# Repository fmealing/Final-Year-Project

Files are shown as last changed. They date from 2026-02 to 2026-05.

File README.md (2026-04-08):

# Ghost Glove

**Progress you can see.**

A smart gym glove that automatically tracks strength training sessions in real time, built as a Final Year Project for MEng Mechatronic and Robotic Engineering at the University of Birmingham.

> By Mealing Labs

---

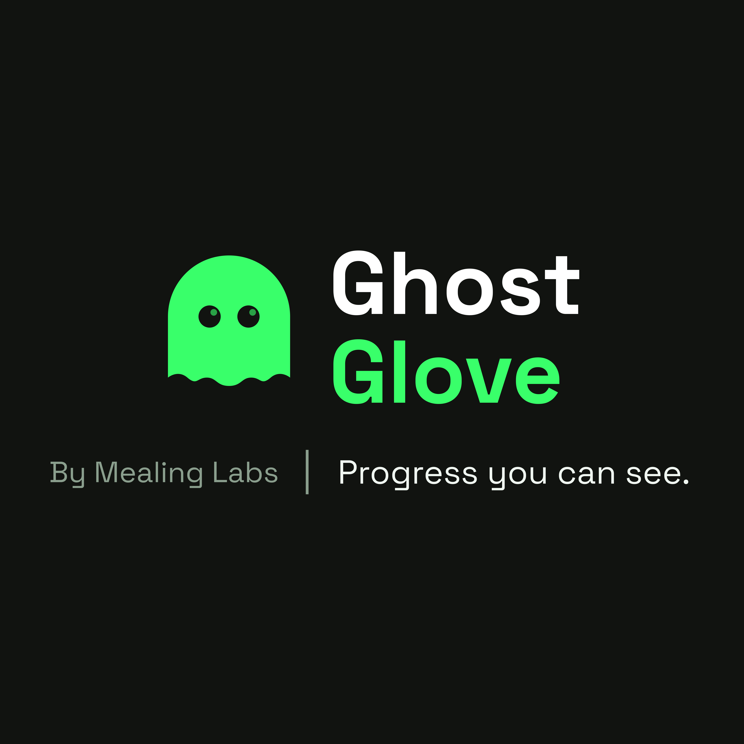
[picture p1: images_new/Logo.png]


---

## The Idea

Most people who join the gym quit. Not because they lack motivation, but because they cannot see the progress. Numbers in a notebook feel abstract. Comparing yourself to others feels worse.

Ghost Glove solves this by changing the question: **what if your only opponent was your past self?**

Every session the glove records your performance and builds a ghost, a data-driven avatar of who you were. Over time, you race against previous versions of yourself. The gap is small at first. But it is real, and you cannot argue with it.

---

## User Story

> Jamie joined the gym in January. Not for the first time. Third time, actually.

Jamie is 24. The first two times he went hard for about three weeks, got bored, stopped seeing the point, and quietly let the membership lapse. This time he bought the glove because his flatmate would not stop talking about it.

**Day 1**<br>
He opens the app, pairs the glove, and gets told something he does not expect. "Your first session builds your opponent." There is no pressure, no benchmark to hit. He just trains, and the app watches. At the end he sees his avatar for the first time: weak, minimal gear, barely any aura. The app tells him: "This is January Jamie. You are going to make him irrelevant." He thinks it is a bit corny. He also screenshots it.

**Week 1**<br>
He trains twice. Nothing dramatic. The audio cues during sets are strange at first. But on his third session it tells him "you slowed down here last time" at rep six of a dumbbell row, and he pushes to rep eight out of pure stubbornness. He does not think much of it in the moment. But he remembers it on the walk home.

**Week 2**<br>
His consistency gear updates. Small change to the avatar, slightly better armour. He notices. He has not missed a session yet and the app reflects that without making a big deal of it. He shows his flatmate. His flatmate points out his ghost still looks terrible. Jamie goes to the gym the next morning.

**Week 3**<br>
First real ghost comparison drops. Current Jamie vs Week 1 Jamie on the same exercise. The gap is small but real: three more quality reps at the same weight. At the end of the set the app says: "you beat him." No fanfare. Just that. He stares at his phone for a second. This is the moment, not because the progress is huge, but because for the first time the progress is his, measured against himself.

**Week 6**<br>
Jamie is training three times a week now. He did not decide to; it just happened. Some sessions he loses, and the app does not punish him for it. It just updates the data. He has stopped thinking about what other people in the gym can lift. He has got his own thing to beat.

**Six months in**<br>
The six-month ghost appears for the first time. January Jamie, full avatar, standing next to current Jamie. The difference is visible across all three axes: bigger build, full gear set, bright aura. Jamie sends it to his flatmate without saying anything. His flatmate buys a glove the next day.

---

## User Journey

The journey was designed before a single line of code was written. Three core phases:

| Phase | What Happens |
| --- | --- |
| **Select & Connect** | Choose your workout. App loads your targets. Put on the glove and everything connects automatically. |
| **Track & Respond**  | Reps counted automatically. App tracks proximity to failure in real time. |
| **Review & Evolve**  | Set complete. App adjusts the next target automatically and shows what you achieved. |

User Journey 1
User Journey 2
User Journey 3

_Initial concept sketches, 16/03/26_

---

## Gamification

The core mechanic: **you compete only against past versions of yourself.** Wins are genuine progress, not arbitrary points.

Your avatar evolves across three axes, each mapped to a real training metric:

| Axis | What It Measures | Visual Representation |
| --- | --- | --- |
| **Stronger** | Progressive weight increase | Physical build / muscle mass |
| **Consistent** | Session attendance and streak | Armour quality |
| **Intense** | Effort per session (velocity, proximity to failure) | Aura / energy |

The ghost system operates across two timescales: a **4-week ghost** (your recent self) and a **6-month ghost** (who you were at the start). Beating one feels like momentum. Beating the other feels like transformation.

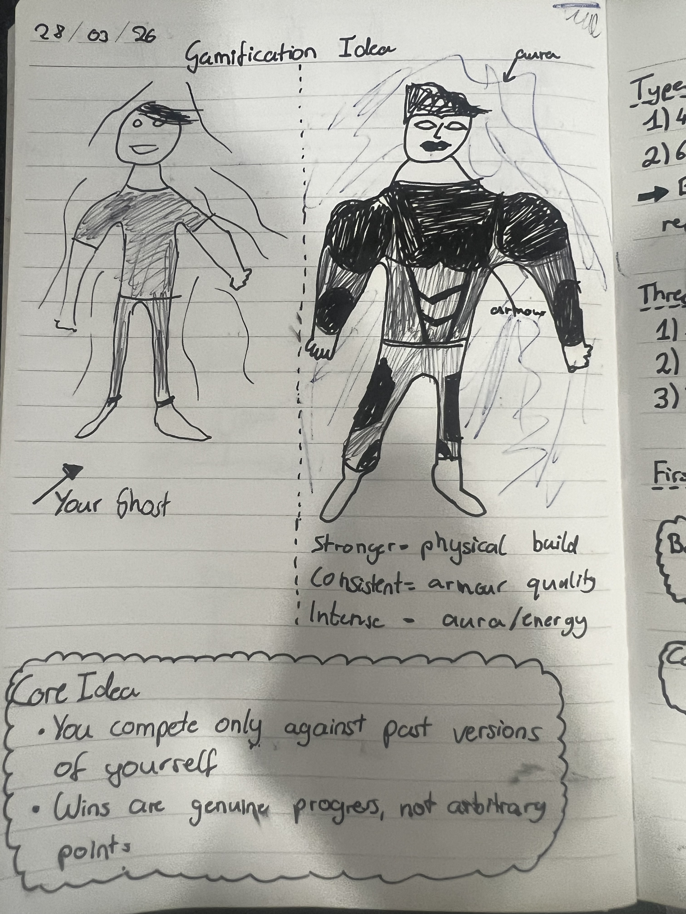
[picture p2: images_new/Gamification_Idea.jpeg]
Gamification Idea Sketch

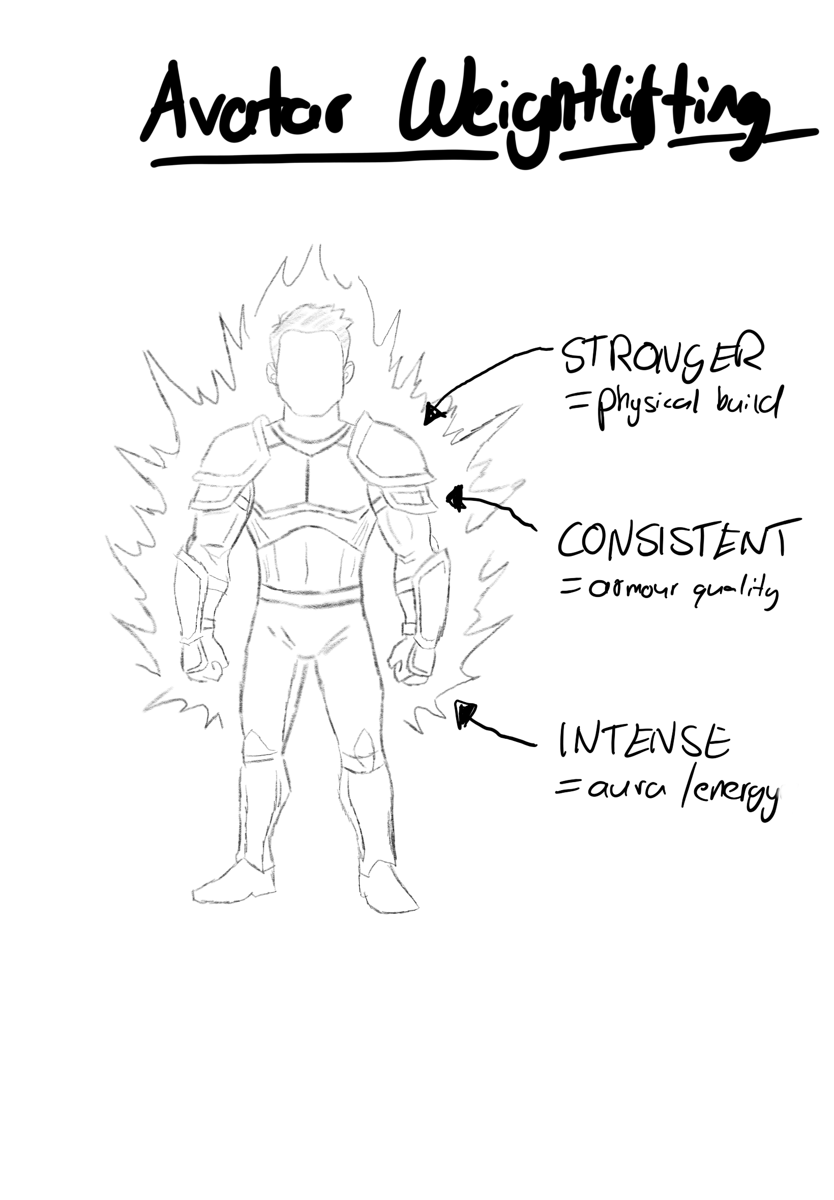
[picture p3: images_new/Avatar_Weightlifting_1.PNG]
Avatar Weightlifting Sketch

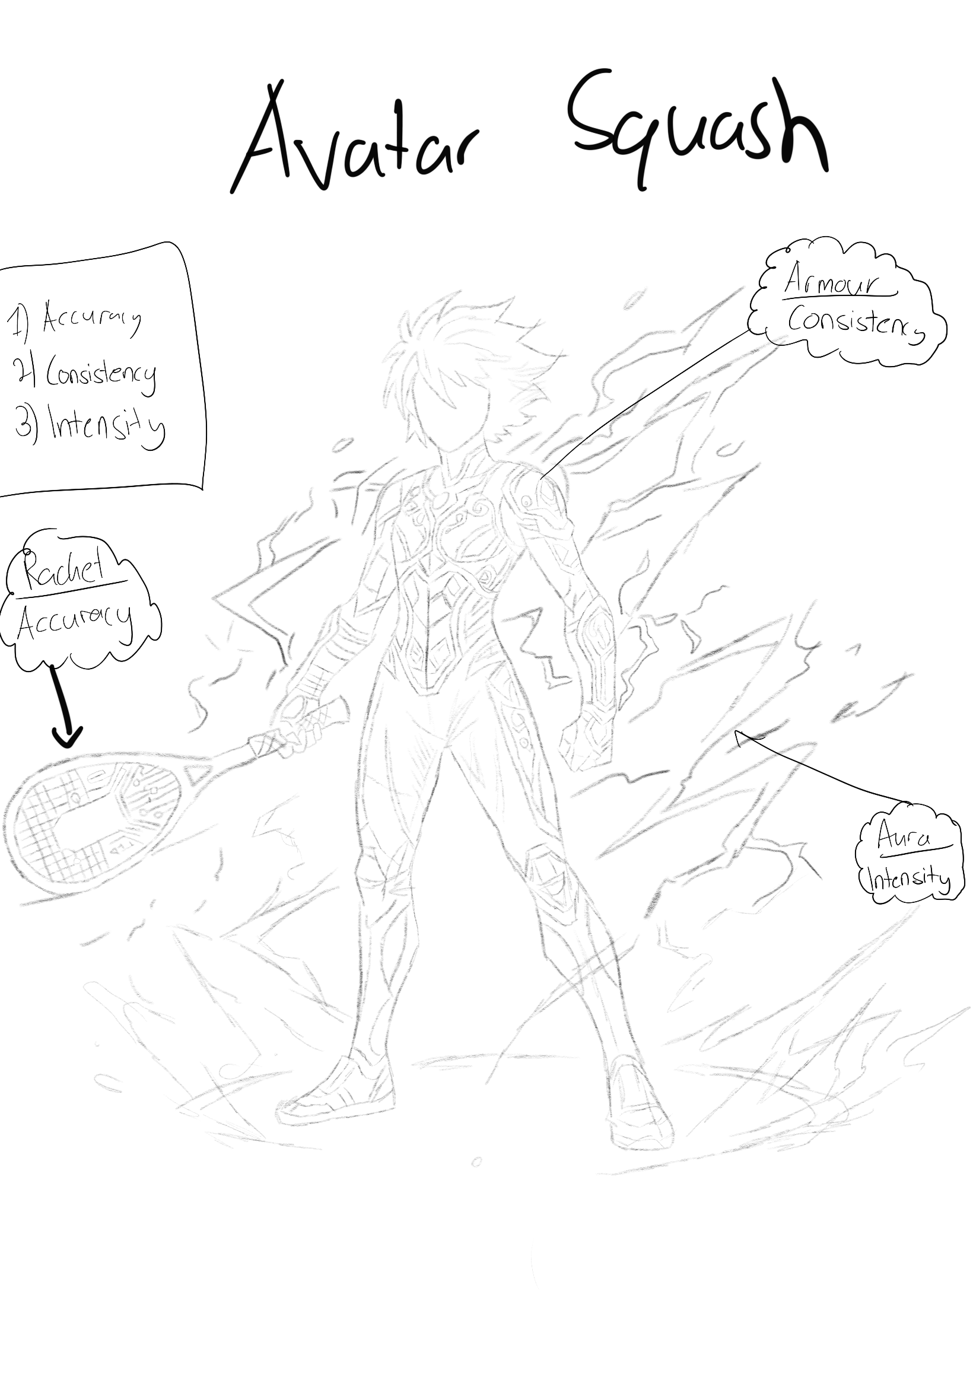
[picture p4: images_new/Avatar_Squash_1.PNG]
Avatar Squash Sketch


_Left: Original gamification concept (28/03/26). Right: Sport-specific avatar sketches. The system is designed to extend beyond weightlifting._

---

## Hardware

Ghost Glove is a fully manufactured smart glove with permanently soldered electronics. The sensor stack:

- **Flex Sensors (x4)**: measure finger bend angle via resistive voltage dividers. Resistor value: 47 kOhm, derived from a geometric mean of approximately 43.3 kOhm, near-optimal for mid-flex sensitivity.
- **MPU-6050 IMU**: 6-DOF accelerometer and gyroscope for wrist orientation and motion. Used for rep counting via a Madgwick filter.
- **ADS1115 ADC**: 16-bit external ADC. Resolves the ADC2/WiFi conflict inherent to the ESP32 by handling all analog reads independently.
- **ESP32-C3 Zero**: the microcontroller. Compact, BLE-capable, runs FreeRTOS with separate sensor tasks.

All components are mounted on a **5 cm x 7 cm veroboard**, permanently soldered and integrated into the glove.

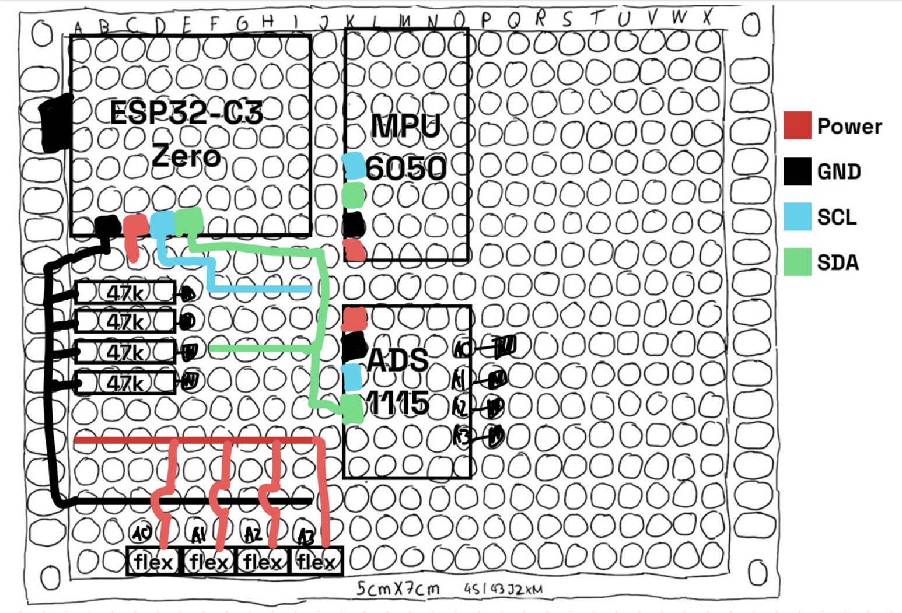
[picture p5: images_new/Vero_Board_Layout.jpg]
Veroboard Layout

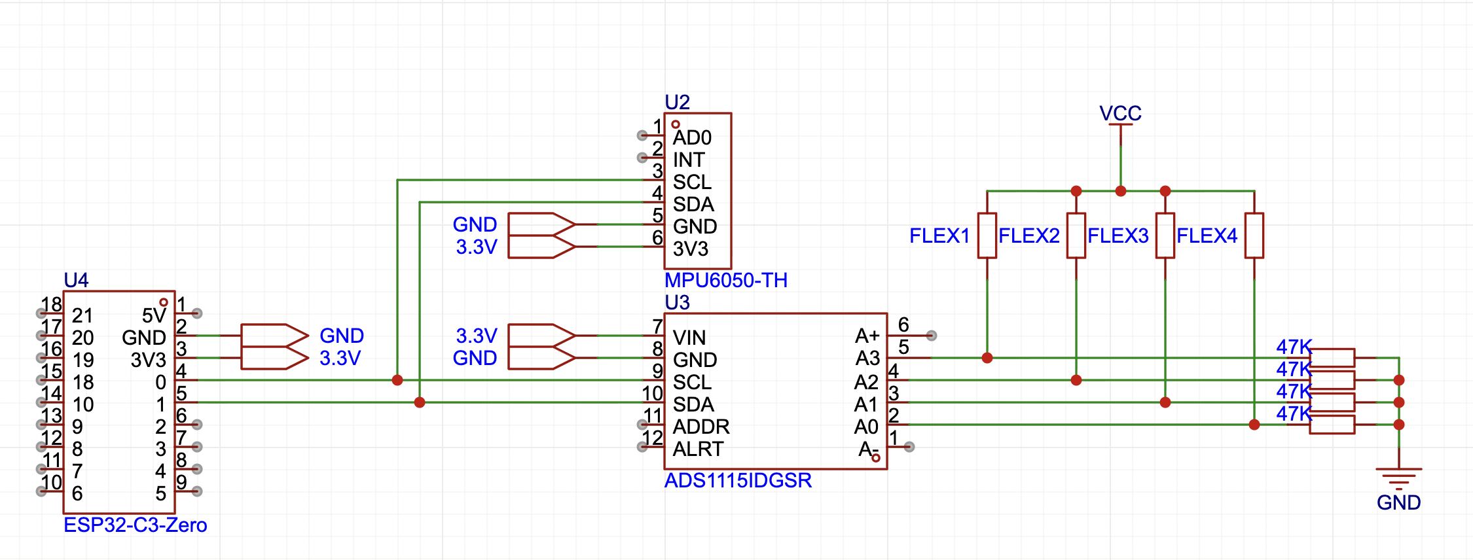
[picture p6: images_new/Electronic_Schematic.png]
Electronic Schematic


_Left: Hand-drawn veroboard layout. Right: EasyEDA schematic showing ESP32-C3 Zero, MPU-6050, ADS1115, and flex sensor voltage dividers._

---

## System Architecture

```
[Flex Sensors] --+
                 +---> [ADS1115 ADC] --+
[MPU-6050 IMU] --+                    |
                                      v
                              [ESP32-C3 Zero]
                              FreeRTOS Tasks:
                              - Sensor read task
                              - IMU read task
                              - MQTT publish task
                                      |
                                      v  MQTT over WiFi
                               [HiveMQ Broker]
                                      |
                                      v
                              [NeonSQL Database]
                                      |
                                      v
                          [Flask API (AWS)] --> [Web Dashboard]
```

Data flow has been validated end-to-end. Upload frequency is approximately 0.31 Hz, with inter-sample jitter of around 237 ms from WiFi scheduling. The live web dashboard displays real-time rep counts and sensor readings.

---

## Software

### Firmware (ESP32-C3 / Arduino)

- **FreeRTOS** task architecture with separate threads for IMU read, ADC read, and MQTT publish
- **Madgwick filter** for orientation estimation from raw IMU data
- **I2C bus** shared between MPU-6050 and ADS1115
- **MQTT** publish to HiveMQ cloud broker

### Backend

- **HiveMQ**: Cloud MQTT broker
- **NeonSQL**: PostgreSQL-compatible serverless database
- **Flask API**: Hosted on AWS, bridges MQTT data to the web dashboard

### Dashboard

Live web interface showing rep counts and sensor readings in real time.

---

## Results

| Metric | Result |
| --- | --- |
| Rep counting accuracy | ~61% (averaged over 4 sets) |
| IMU pipeline | Fully validated; raw accelerometer and gyroscope data confirmed |
| Connectivity | ESP32 to HiveMQ to NeonSQL to Flask to Dashboard: working |
| Upload frequency | ~0.31 Hz |
| Glove manufacture | Veroboard permanently soldered and integrated |
| Flex sensors | Hardware fault under investigation; returning null values |

The system works reliably on slow, controlled reps. Fast or jerky movements cause false positives due to threshold sensitivity. Threshold tuning for dynamic rep detection is the primary in-progress item.

---

## Design System

The app has a defined visual language built to feel like a training tool, not a health tracker.

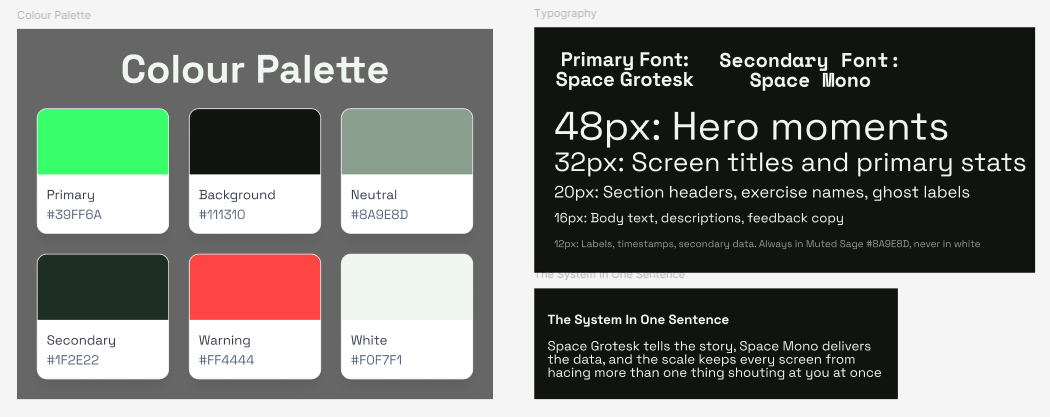
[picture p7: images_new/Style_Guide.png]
Style Guide


| Token | Value |
| --- | --- |
| Primary (Electric Green) | `#39FF6A` |
| Background | `#111310` |
| Secondary | `#1F2E22` |
| Neutral (Muted Sage) | `#8A9E8D` |
| Warning | `#FF4444` |
| Primary Font | Space Grotesk |
| Secondary Font | Space Mono |

Space Grotesk carries the narrative. Space Mono delivers the data. The type scale ensures no single screen has more than one element competing for attention.

---

## Future Work

### Hardware

- [x] Resolve flex sensor hardware fault and investigate null value root cause
- [ ] Custom PCB to replace veroboard and reduce enclosure size
- [ ] Piezoresistive TPU filament as an alternative flex sensing material
- [ ] Pressure Sensor Design 2: per-finger air bladder system with thin-profile construction

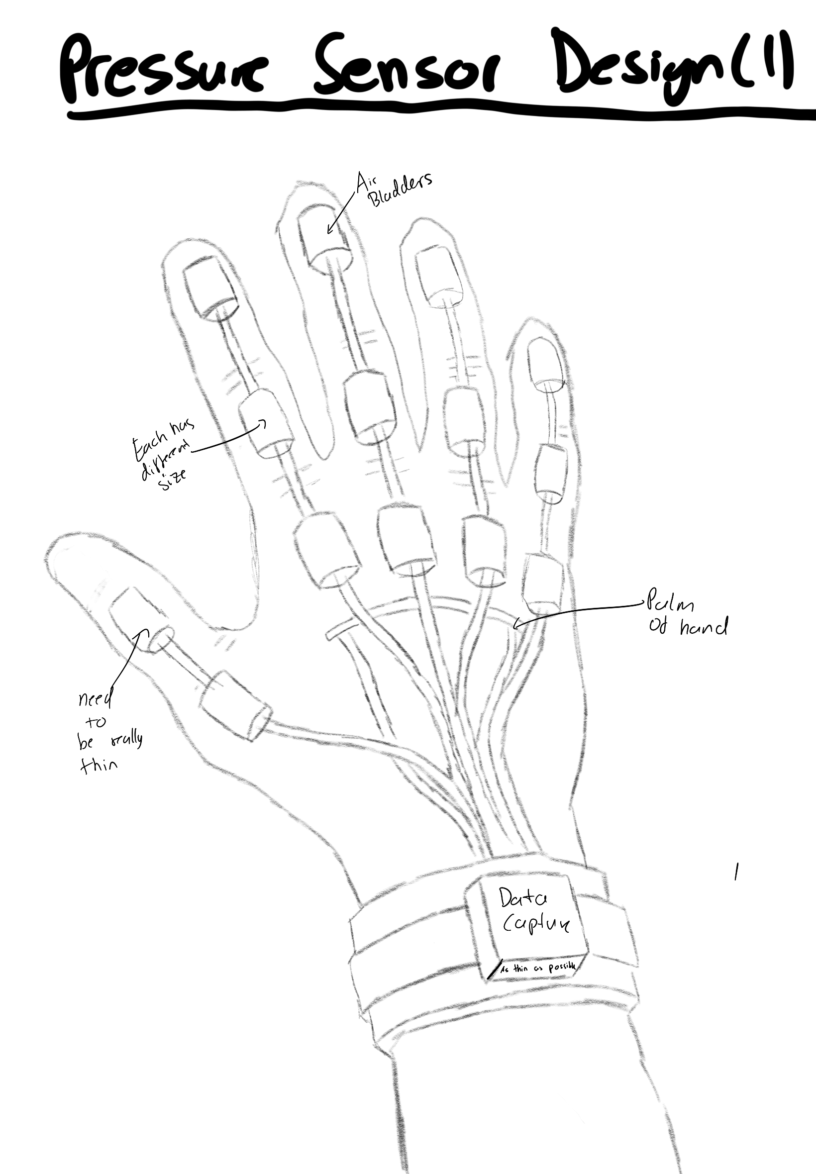
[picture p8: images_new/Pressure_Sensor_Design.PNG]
Pressure Sensor Design


_V3 concept: per-finger air bladders with joint-level pressure sensing. Each bladder is sized differently and routes to a wrist-mounted data capture unit._

### Software

- [ ] Threshold tuning for dynamic rep detection
- [ ] Matrix profiling for weight estimation from sensor data
- [ ] Ghost avatar system (4-week and 6-month comparisons)
- [ ] Mobile app (React Native) with Hale health score integration
- [ ] BLE transport to replace WiFi/MQTT for lower latency

---

## Academic Context

This project was submitted as a Final Year Project for the MEng Mechatronic and Robotic Engineering degree at the University of Birmingham, under the supervision of **Dr Mahvish Nazir**.

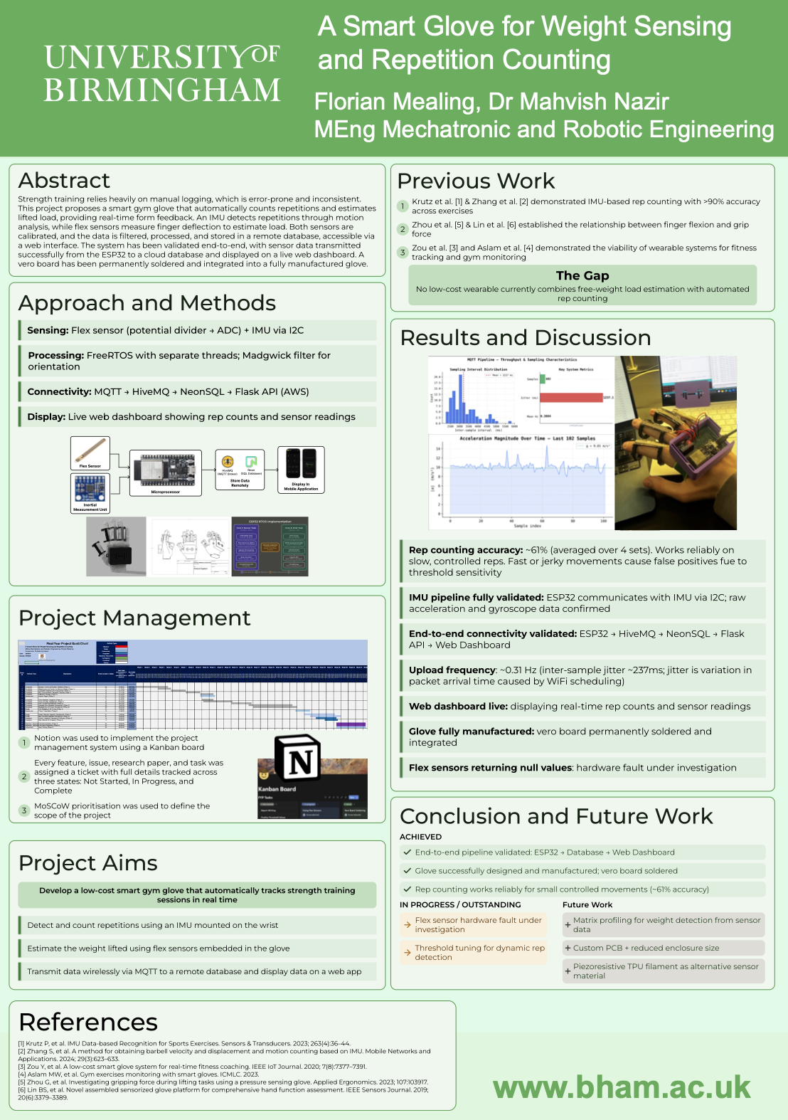
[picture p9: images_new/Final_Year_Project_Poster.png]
FYP Poster


**TRL Assessment: TRL 3**: subsystems validated independently. Simultaneous flex sensor and IMU transmission has been identified as the key hardware blocker preventing TRL 4.

**Project management:** Notion Kanban board with MoSCoW prioritisation. Every feature, issue, research paper, and task tracked across Not Started / In Progress / Complete.

---

## References

1. Krutz P, et al. _IMU Data-based Recognition for Sports Exercises._ Sensors & Transducers. 2023.
2. Zhang S, et al. _A method for obtaining barbell velocity and displacement and motion counting based on IMU._ Mobile Networks and Applications. 2024.
3. Zou Y, et al. _A low-cost smart glove system for real-time fitness coaching._ IEEE IoT Journal. 2020.
4. Aslam MW, et al. _Gym exercises monitoring with smart gloves._ ICMLC. 2023.
5. Zhou G, et al. _Investigating gripping force during lifting tasks using a pressure sensing glove._ Applied Ergonomics. 2023.
6. Lin BS, et al. _Novel assembled sensorized glove platform for comprehensive hand function assessment._ IEEE Sensors Journal. 2019.

---

## Author

**Florian Mealing** -- MEng Mechatronic and Robotic Engineering, University of Birmingham (2022--2026)

- [florianmealing.com](https://florianmealing.com)
- [LinkedIn](https://linkedin.com/in/florianmealing)
- [YouTube](https://www.youtube.com/@florianmealing)

---



_By Mealing Labs_

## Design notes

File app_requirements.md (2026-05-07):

# Ghost Glove — App & Backend Requirements

> For Claude Code. App-side only. ESP32 firmware is out of scope for this document.

---

## ⚠️ Architecture Change Notice

**The previous implementation had the ESP32 make direct API calls over WiFi. This is no longer the case.**

The data pipeline has fundamentally changed:

```
OLD: ESP32 → WiFi → API → NeonSQL
NEW: ESP32 → BLE → Mobile App → Backend API → NeonSQL
```

The **HiveMQ MQTT broker** and **NeonSQL database** are being retained, but the ESP32 no longer connects to them directly. The mobile app now owns the BLE connection and is responsible for forwarding data upstream.

Any existing code that assumed ESP32 → API direct calls should be treated as deprecated and replaced.

---

## BLE Data Packet

The ESP32 transmits a single structured packet per rep/interval over BLE. The app must parse this packet:

| Field | Type | Notes |
| --- | --- | --- |
| `accel_x` | float  | m/s² |
| `accel_y` | float  | m/s² |
| `accel_z` | float  | m/s² |
| `gyro_x` | float  | deg/s |
| `gyro_y` | float  | deg/s |
| `gyro_z` | float  | deg/s |
| `flex_1` | float  | Thumb (raw ADC or mapped voltage) |
| `flex_2` | float  | Index |
| `flex_3` | float  | Middle |
| `flex_4` | float  | Ring |
| `rep_count` | int | Cumulative rep count from ESP32 |
| `timestamp` | uint32 | Milliseconds since session start (used for speed/tempo analysis) |

---

## Tech Stack

- **Framework:** React Native (Expo) — consistent with existing Hale app work
- **BLE:** `react-native-ble-plx` or Expo's BLE module
- **Backend:** New lightweight backend, **hosted for free** (options: Railway free tier, Render free tier, or Supabase Edge Functions)
- **Database:** NeonSQL (existing, retain)
- **Broker:** HiveMQ (existing, retain) — app publishes to MQTT topics via backend or directly
- **Fonts:** Space Grotesk (primary), Space Mono (secondary) — load via `@expo-google-fonts`

---

## Design System

Match the Ghost Glove brand style guide exactly:

### Colours

```js
const colours = {
  primary: "#39FF6A", // Electric green — CTAs, active states, highlights
  background: "#111310", // Near-black — all screens
  secondary: "#1F2E22", // Dark green — cards, panels
  neutral: "#8A9E8D", // Muted sage — labels, timestamps, secondary data (NEVER white at 12px)
  warning: "#FF4444", // Red — errors, alerts
  white: "#F0F7F1", // Off-white — body text
};
```

### Typography

```js
// All sizes in px (React Native: use these as fontSize values)
const type = {
  hero: 48, // Space Grotesk Bold — hero moments only
  title: 32, // Space Grotesk — screen titles, primary stats
  sectionHeader: 20, // Space Grotesk — section headers, exercise names, ghost labels
  body: 16, // Space Grotesk — body text, descriptions, feedback copy
  label: 12, // Space Mono — labels, timestamps, secondary data
  // ⚠️ Always render 12px in neutral (#8A9E8D), never white
};
```

### Design Principles

- Dark background on all screens (`#111310`)
- Minimal, clean — no visual clutter
- Primary green used sparingly as accent only
- Space Mono for all data readouts (monospaced for alignment)
- Space Grotesk for all narrative/UI text

---

## App Architecture (Data Flow)

```
ESP32-C3 (BLE peripheral)
    │
    │  BLE characteristic notify
    ▼
Mobile App (BLE central)
    ├── Parse BLE packet
    ├── Run flex sensor position lookup (finger mapping)
    ├── Display live values (IMU + flex)
    ├── Display rep count
    ├── Maintain ring buffer (last N packets)
    └── On session end / buffer flush → HTTP POST to Backend
            │
            ▼
        Backend API (free-hosted)
            ├── Receive session data
            ├── POST to NeonSQL (session records, rep logs)
            ├── Publish summary to HiveMQ MQTT topic
            └── Future: intensity calculations, ghost comparison data
```

---

## Feature Requirements

### F1 — BLE Connection

- Scan for and connect to ESP32-C3 peripheral (device name: `GhostGlove` or configurable)
- Subscribe to BLE characteristic for data notifications
- Handle reconnection gracefully (auto-reconnect on drop)
- Show connection status indicator on all screens

### F2 — Flex Sensor Display & Finger Position Lookup

- Display raw flex sensor values for all 4 sensors (Thumb, Index, Middle, Ring)
- Apply lookup table to map ADC/voltage value → finger position label
  - Position states (to define with lookup thresholds): `EXTENDED`, `PARTIAL`, `BENT`, `CLOSED`
  - Thresholds TBD via calibration — implement as a configurable constant object
- Display both raw value and mapped position label in the UI
- Visual representation of hand/finger state (simple indicator, not necessarily a 3D model at this stage)

### F3 — IMU Display

- Live display of all 6 IMU values (accel XYZ, gyro XYZ)
- Use Space Mono font for numerical readouts
- Update in real-time as BLE packets arrive

### F4 — Rep Counter Display

- Display current rep count (sourced from ESP32 packet, not recounted in app)
- Large, prominent — 48px hero treatment
- Session total visible at all times during active session

### F5 — Session Ring Buffer

- Maintain a rolling ring buffer of the last N BLE packets (N = configurable, default 300)
- Buffer used to batch-upload to backend without overwhelming the API on every packet
- Flush buffer: on session end, or when buffer hits max capacity, or on manual trigger

### F6 — Data Export — IMU Graph

- Generate a time-series graph of IMU data from session buffer
- Axes: time (x), acceleration/gyro values (y)
- Export as image (PNG) or shareable format
- Library: `react-native-chart-kit` or `Victory Native`

### F7 — Data Export — Flex Sensor Graph

- Generate time-series graph of all 4 flex sensor channels
- Same export mechanism as F6

### F8 — Backend Integration

- New backend service, hosted for free (Railway / Render / Supabase Edge Functions — pick one)
- Endpoints required:
  - `POST /session` — upload a completed session (metadata + packet array)
  - `GET /sessions` — retrieve historical sessions for a user
  - `GET /session/:id` — retrieve a specific session with full packet data
- Backend writes to NeonSQL and publishes summary to HiveMQ
- App authenticates requests with a simple API key or JWT (TBD)

### F9 — Historical Data View

- View past sessions retrieved from backend
- Show: date, rep count, session duration
- Tap to expand: view IMU + flex graphs for that session

---

## Screen Map

```
App
├── Home / Dashboard
│   ├── Connect button (BLE status)
│   ├── Last session summary
│   └── Start Session CTA
│
├── Live Session Screen
│   ├── Rep Counter (hero, 48px)
│   ├── Flex Sensor Panel (4 sensors, value + position label)
│   ├── IMU Panel (6 values, live)
│   └── End Session button
│
├── Session Review Screen
│   ├── Rep total
│   ├── IMU graph (exportable)
│   ├── Flex sensor graph (exportable)
│   └── Upload to backend / Save locally
│
└── History Screen
    ├── Session list
    └── Session detail (graphs + stats)
```

---

## Out of Scope (This Document)

- ESP32 firmware (separate requirements doc)
- Ghost avatar / gamification layer (future milestone)
- User authentication / accounts (future milestone)
- Anything related to the old WiFi / direct API call architecture

---

## Notes for Implementation

- Prioritise getting BLE parsing and live display working first (F1–F4) before backend work
- The flex sensor lookup table thresholds will need calibration passes — build the system as configurable from day one, not hardcoded
- Keep backend minimal — it only needs to store and retrieve data at this stage; intensity calculations are a future concern
- Ring buffer implementation should be decoupled from the display layer so it can be flushed independently
- Use NativeWind for stling, not CSS

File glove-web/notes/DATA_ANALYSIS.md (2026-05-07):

# Ghost Glove — Data Analysis Guide

Two data-collection tools are built into the glove-web dashboard.
Access them via the **Calibration** and **Latency** tabs in the nav bar.

> **Requirements:** Chrome or Edge (Web Bluetooth). Glove firmware flashed and advertising as `GhostGlove`.

---

## Experiment 1 — Flex Sensor Characterisation (`/calibration`)

### Purpose

Determine the raw ADS1115 ADC count range for each finger across six known
hand positions. The resulting min/max values feed directly into
`lib/flexCalibration.ts` to calibrate the flex bars on the dashboard.

### Hand Positions

| Label | Description |
| --- | --- |
| Hand flat on table | Fingers fully extended, palm down |
| 50 mm tube | Hand curled around a 50 mm diameter cylinder |
| 40 mm tube | Hand curled around a 40 mm diameter cylinder |
| 30 mm tube | Hand curled around a 30 mm diameter cylinder |
| 20 mm tube | Hand curled around a 20 mm diameter cylinder |
| Fist | Hand fully closed |

### Procedure

1. Open the **Calibration** tab.
2. Click **Connect Glove** and select `GhostGlove` from the browser dialog.
3. Select a hand position using the position buttons.
4. Hold your hand in that position (keep it still).
5. Click **Start Capture** — a 3-second countdown plays, then 10 seconds of
   data are recorded automatically.
6. When the capture finishes, inspect the per-finger stats table (min, max,
   range, mean). The chart shows all four flex sensors over the capture window.
7. Click **Export CSV** to download the raw time-series for that position.
8. Repeat steps 3–7 for every position.
9. Once all positions are captured, click **Export All CSV** in the
   _All Captures — Summary_ table to download a single summary file.

### Repeatability Check

To test repeatability:

1. Remove the glove, put it back on, repeat the same position.
2. Compare the new capture's min/max against the first. A stable sensor will
   show <5% deviation in mean ADC value between wearings.

### CSV Format

**Per-position file** (`flex_<position>.csv`):

```
t_s,flex_ring,flex_middle,flex_index,flex_thumb
0.000,4102,7543,4012,6311
0.020,4098,7551,4008,6298
...
```

**Summary file** (`flex_calibration_summary.csv`):

```
position,ring_min,ring_max,ring_range,ring_mean,middle_min,...
Hand flat on table,3901,4203,302,4052.1,...
50 mm tube,...
```

### Updating Calibration

After completing all captures, open `lib/flexCalibration.ts` and update
`FLEX_RANGES` with the observed min (flattest position) and max (fist) per finger:

```ts
export const FLEX_RANGES = {
  ring:   { min: <flat_min>, max: <fist_max> },
  middle: { min: <flat_min>, max: <fist_max> },
  index:  { min: <flat_min>, max: <fist_max> },
  thumb:  { min: <flat_min>, max: <fist_max> },
} as const;
```

---

## Experiment 2 — BLE Latency Analysis (`/latency`)

### Purpose

Measure the end-to-end delay between the ESP32 transmitting a BLE NOTIFY
packet and the browser receiving it. Reports mean, min, max, and standard
deviation.

### Method

The ESP32 timestamps each packet as `millis() - sessionStart` (ms since BLE
connection). The browser records the GATT connection time (`connectedAt`).
For each arriving packet:

```
latency_ms = Date.now() - connectedAt - packet.timestamp
```

This isolates the BLE transmission + OS scheduling delay, independent of
wall-clock differences between the ESP32 and the host machine.

### Procedure

1. Open the **Latency** tab.
2. Click **Connect Glove**.
3. Click **Start Recording** — packets are captured continuously.
4. Move naturally for 30–60 seconds (or as long as required).
5. Click **Stop** — the chart and statistics table appear.
6. Click **Export CSV** to download the full latency log.

### Interpreting the Chart

- **Flat, low line** — consistent low latency. Expected: 10–50 ms range.
- **Occasional spikes** — BLE connection events or OS scheduling jitter.
- **Upward drift** — clock skew between ESP32 crystal and system clock
  accumulating over a long session. Acceptable for sessions under 5 minutes.

### CSV Format

`ble_latency.csv`:

```
seq,esp_timestamp_ms,latency_ms
0,20,18.00
1,40,17.50
2,60,19.20
...
```

| Column | Description |
| --- | --- |
| `seq` | Packet sequence number (0-indexed) |
| `esp_timestamp_ms` | `millis() - sessionStart` from firmware |
| `latency_ms` | Computed transmission delay |

### Notes

- Packets with `latency_ms < 0` or `> 2000` are automatically discarded
  (clock alignment artefacts at session start).
- Run the experiment with the glove in typical use conditions — laptop on desk,
  glove worn normally — to get representative figures.
- Repeat the experiment 3× and average the means for a more robust result.

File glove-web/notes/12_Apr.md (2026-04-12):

## Flex sensor ranges

### Thumb

- Max: 9100
- Min: 4500

### Index

- Max: 5300
- Min: 3000

### Middle

- Max: 10000
- Min: 6300

### Ring

- Max: 5200
- Min: 3900

really small ranges, need to tune resistors

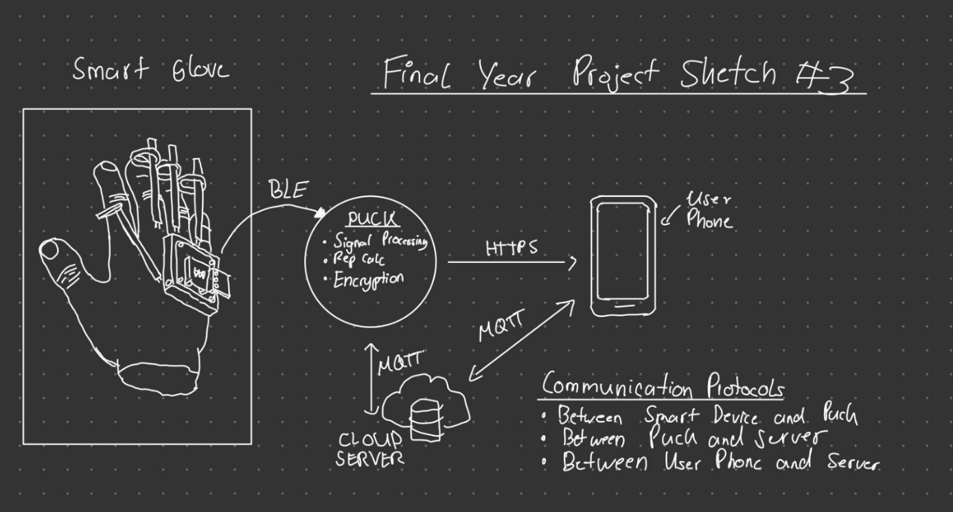
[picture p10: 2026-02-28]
images/architecture.png

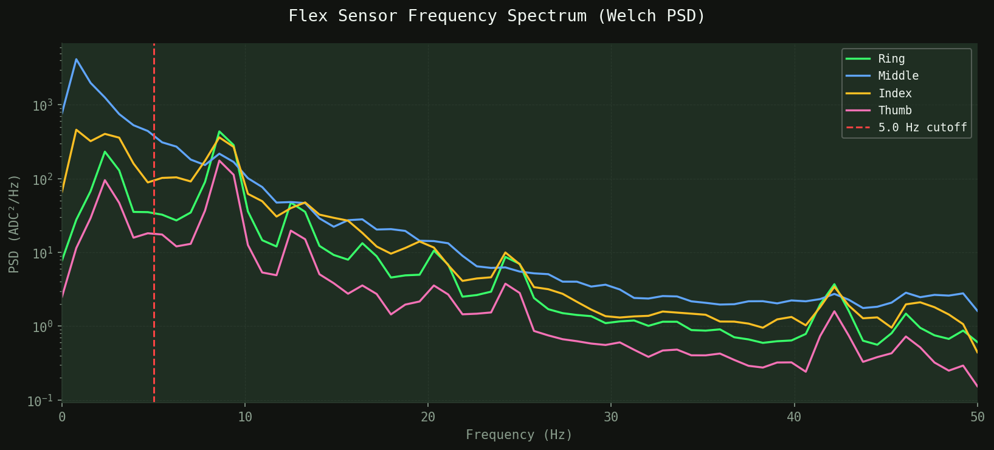
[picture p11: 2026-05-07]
calibration/plots/flex_frequency_spectrum.png

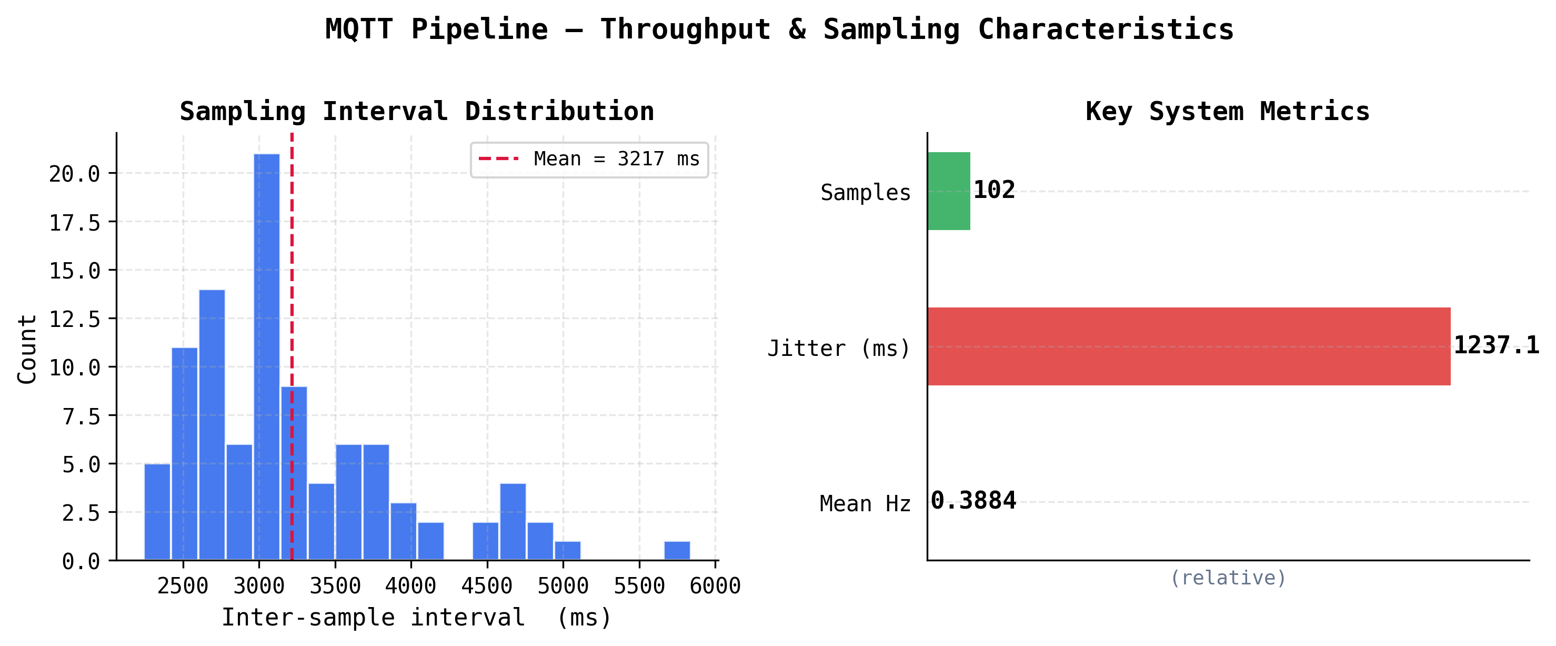
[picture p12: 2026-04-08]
analytics/figures/fig5_throughput_summary.png

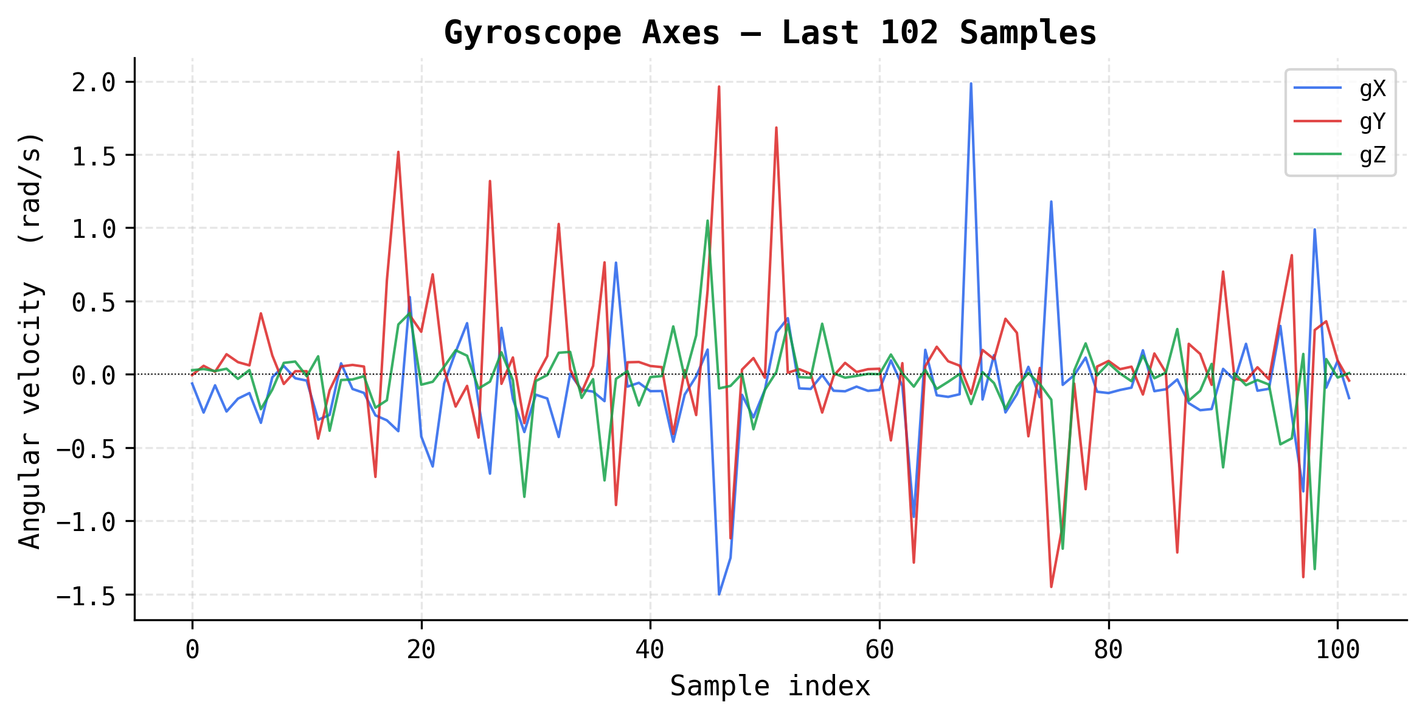
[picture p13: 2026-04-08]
analytics/figures/fig3_gyro_timeseries.png

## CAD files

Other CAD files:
CAD/Workout Glove Concept.f3z
CAD/finger rings v1.f3d

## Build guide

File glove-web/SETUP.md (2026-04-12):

# Ghost Glove — Setup Guide

## What you need

- ESP32-C3 dev board
- MPU6050 (I2C, address `0x68`)
- ADS1115 ADC (I2C, address `0x48`)
- 4× flex sensors wired to ADS1115 channels A0–A3
- USB cable (to flash the firmware)
- Chrome or Edge browser (Web Bluetooth is not supported in Firefox or Safari)

---

## 1. Wire the hardware

| Signal | ESP32-C3 pin |
|---|---|
| SDA | GP1 (pin 4) |
| SCL | GP0 (pin 5) |
| 3.3 V  | 3V3 |
| GND | GND |

Both the MPU6050 and ADS1115 share the same I2C bus (SDA/SCL). Connect them in parallel.

Flex sensors connect to a voltage divider feeding ADS1115 channels A0–A3.

---

## 2. Install Arduino IDE board support

1. Open **Arduino IDE → Preferences**
2. Paste the following into **Additional Boards Manager URLs**:
   ```
   https://raw.githubusercontent.com/espressif/arduino-esp32/gh-pages/package_esp32_index.json
   ```
3. Go to **Tools → Board → Boards Manager**, search `esp32`, and install **esp32 by Espressif Systems**

---

## 3. Install Arduino libraries

In **Tools → Manage Libraries**, install all three:

| Library | Author |
|---|---|
| Adafruit MPU6050 | Adafruit |
| Adafruit Unified Sensor | Adafruit |
| Adafruit ADS1X15 | Adafruit |

The BLE library (`BLEDevice.h`) ships with the ESP32 board core — no separate install needed.

---

## 4. Flash the firmware

1. Open `arduino/esp32_c3_sensors/esp32_c3_sensors.ino` in Arduino IDE
2. Select board: **Tools → Board → ESP32 Arduino → ESP32C3 Dev Module**
3. Select the correct port under **Tools → Port**
4. Click **Upload**
5. Open **Tools → Serial Monitor** at **115200 baud** — you should see:

   ```
   [OK] MPU6050 ready
   [OK] ADS1115 ready
   [OK] BLE advertising as 'GhostGlove'
   --- Live Readings (~50 Hz) ---
   ```

The glove is now advertising over BLE. You can unplug the USB and power it from a battery — it will start advertising automatically on boot.

---

## 5. Run the website

```bash
cd glove-web
npm install
npm run dev
```

Open [http://localhost:3000](http://localhost:3000) in **Chrome or Edge**.

---

## 6. Connect in the browser

1. Click **Connect Glove** in the top-right corner
2. A browser dialog will appear scanning for BLE devices — select **GhostGlove**
3. Click **Pair**

The dashboard will start showing live data immediately:

- **Rep Count** — increments as the glove detects reps
- **Flex Sensors** — raw ADC readings (0–32767) for each finger, shown as progress bars
- **Accelerometer** — X/Y/Z in m/s²
- **Gyroscope** — X/Y/Z in rad/s
- **T+** — elapsed session time in seconds

---

## Troubleshooting

**"Web Bluetooth is not supported"** — switch to Chrome or Edge. Safari and Firefox do not support Web Bluetooth.

**Device not appearing in the browser dialog** — make sure the Serial Monitor is closed (it may hold the USB port), confirm the firmware uploaded successfully, and check that you see `[OK] BLE advertising` in Serial Monitor before disconnecting USB.

**Sensors read zero or garbage** — check I2C wiring (SDA/SCL swapped is common). Confirm MPU6050 is at `0x68` and ADS1115 is at `0x48` using an I2C scanner sketch.

**Flex bars show no movement** — the ADS1115 reads signed int16, so the effective range in single-ended mode is 0–32767. If all readings sit at zero, check the flex sensor voltage divider circuit.

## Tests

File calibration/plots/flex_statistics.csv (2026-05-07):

Position | Finger | N | Mean | Std Dev | Min | Max | Range | Median
Flat | Ring | 1760 | 5134.7 | 49.8 | 5010 | 5258 | 248 | 5136.0
Flat | Middle | 1760 | 9415.9 | 125.1 | 8706 | 9629 | 923 | 9432.0
Flat | Index | 1760 | 4994.6 | 79.4 | 4636 | 5165 | 529 | 5007.0
Flat | Thumb | 1760 | 8542.1 | 37.4 | 8412 | 8627 | 215 | 8548.0
50 mm | Ring | 1759 | 4700.9 | 81.3 | 4498 | 4875 | 377 | 4700.0
50 mm | Middle | 1759 | 6741.4 | 124.2 | 6188 | 6972 | 784 | 6771.0
50 mm | Index | 1759 | 3858.8 | 115.7 | 3440 | 4107 | 667 | 3863.0
50 mm | Thumb | 1759 | 6315.8 | 81.0 | 6038 | 6493 | 455 | 6328.0
40 mm | Ring | 1760 | 4690.8 | 81.3 | 4494 | 4885 | 391 | 4690.0
40 mm | Middle | 1760 | 6634.6 | 229.7 | 5912 | 6998 | 1086 | 6688.0
40 mm | Index | 1760 | 3772.0 | 122.9 | 3351 | 4060 | 709 | 3777.0
40 mm | Thumb | 1760 | 6593.4 | 69.5 | 6383 | 6757 | 374 | 6595.0
30 mm | Ring | 1759 | 4674.8 | 93.6 | 4456 | 4865 | 409 | 4678.0
30 mm | Middle | 1759 | 6099.4 | 341.3 | 5022 | 6628 | 1606 | 6093.0
30 mm | Index | 1759 | 3521.6 | 127.1 | 3171 | 3877 | 706 | 3511.0
30 mm | Thumb | 1759 | 6368.9 | 154.0 | 6117 | 6594 | 477 | 6311.0
20 mm | Ring | 1760 | 4727.9 | 80.0 | 4565 | 4945 | 380 | 4725.0
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

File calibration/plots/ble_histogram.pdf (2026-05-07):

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

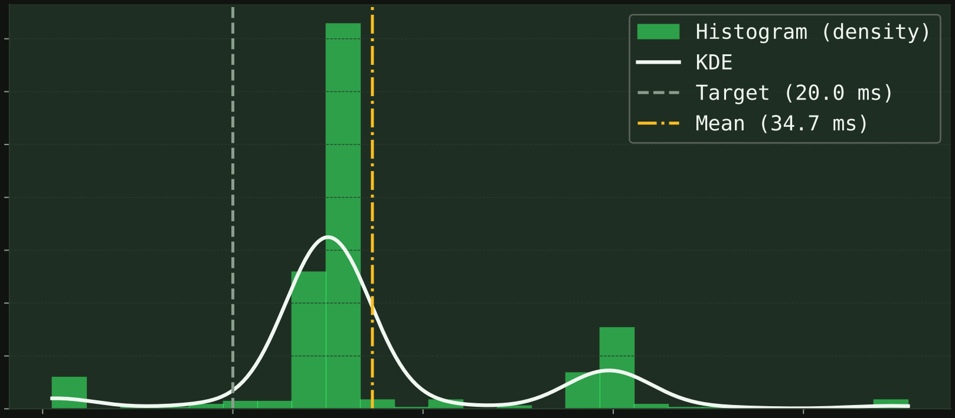
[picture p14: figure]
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

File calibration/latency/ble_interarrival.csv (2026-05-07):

# Ghost Glove BLE Inter-Arrival Time Log
# arrival_ms = ms since recording started (browser clock)
# esp_timestamp_ms = ms since BLE connect (ESP32 clock)
# interarrival_ms = time between consecutive packet arrivals (blank for first packet)
# target: 20 ms (50 Hz)
seq | arrival_ms | esp_timestamp_ms | interarrival_ms
0 | 55 | 59014
1 | 86 | 59048 | 31.00
2 | 115 | 59082 | 29.00
3 | 147 | 59115 | 32.00
4 | 175 | 59149 | 28.00
5 | 206 | 59183 | 31.00
6 | 236 | 59217 | 30.00
7 | 295 | 59251 | 59.00
8 | 326 | 59286 | 31.00
9 | 355 | 59320 | 29.00
10 | 385 | 59354 | 30.00
11 | 417 | 59388 | 32.00
12 | 445 | 59422 | 28.00
13 | 475 | 59456 | 30.00
14 | 505 | 59490 | 30.00
15 | 565 | 59524 | 60.00
16 | 596 | 59558 | 31.00
17 | 626 | 59592 | 30.00
18 | 685 | 59625 | 59.00
19 | 686 | 59659 | 1.00
20 | 716 | 59694 | 30.00
21 | 745 | 59727 | 29.00
22 | 806 | 59762 | 61.00
23 | 895 | 59796 | 89.00
24 | 896 | 59829 | 1.00
25 | 897 | 59863 | 1.00
26 | 925 | 59897 | 28.00
27 | 955 | 59931 | 30.00
28 | 986 | 59966 | 31.00
29 | 1016 | 60000 | 30.00
30 | 1105 | 60034 | 89.00
31 | 1106 | 60068 | 1.00
32 | 1135 | 60102 | 29.00
33 | 1165 | 60135 | 30.00
34 | 1195 | 60170 | 30.00
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

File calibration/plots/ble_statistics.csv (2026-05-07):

Metric | Value
Total packets recorded | 498
Valid inter-arrival intervals | 488
Mean inter-arrival (ms) | 34.672
Median (ms) | 30.000
Std Dev / Jitter (ms) | 14.883
Variance (ms²) | 221.498
Min (ms) | 1.000
Max (ms) | 91.000
P5 (ms) | 17.350
P25 (ms) | 29.000
P75 (ms) | 32.000
P95 (ms) | 61.000
IQR (ms) | 3.000
Effective frequency (Hz) | 28.842
On-time within ±5.0 ms of 20.0 ms | 2.5%
Shapiro-Wilk p (normality test) | 0.0000

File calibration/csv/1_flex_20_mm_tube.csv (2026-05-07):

# Ghost Glove Flex Calibration — 20 mm tube
t_s | flex_ring | flex_middle | flex_index | flex_thumb
0.045 | 4710 | 6356 | 3632 | 6182
0.074 | 4790 | 6493 | 3661 | 6124
0.104 | 4716 | 6444 | 3807 | 6203
0.135 | 4608 | 6374 | 3688 | 6185
0.168 | 4659 | 6314 | 3648 | 6175
0.239 | 4740 | 6428 | 3665 | 6119
0.239 | 4736 | 6498 | 3757 | 6180
0.284 | 4596 | 6392 | 3683 | 6193
0.314 | 4719 | 6456 | 3558 | 6155
0.345 | 4815 | 6436 | 3667 | 6184
0.374 | 4693 | 6409 | 3688 | 6235
0.405 | 4703 | 6530 | 3568 | 6185
0.435 | 4836 | 6535 | 3653 | 6170
0.494 | 4728 | 6630 | 3773 | 6216
0.524 | 4659 | 6542 | 3642 | 6197
0.555 | 4753 | 6604 | 3645 | 6124
0.584 | 4714 | 6696 | 3725 | 6182
0.615 | 4601 | 6599 | 3661 | 6196
0.644 | 4719 | 6593 | 3550 | 6146
0.685 | 4778 | 6838 | 3684 | 6190
0.707 | 4673 | 6740 | 3687 | 6237
0.736 | 4718 | 6731 | 3568 | 6179
0.794 | 4839 | 6597 | 3653 | 6180
0.832 | 4715 | 6662 | 3765 | 6215
0.884 | 4648 | 6654 | 3648 | 6198
0.885 | 4762 | 6660 | 3653 | 6141
0.914 | 4722 | 6819 | 3770 | 6200
0.944 | 4610 | 6764 | 3683 | 6183
0.974 | 4720 | 6782 | 3559 | 6151
1.035 | 4775 | 6883 | 3697 | 6198
1.064 | 4672 | 6742 | 3687 | 6254
1.094 | 4719 | 6683 | 3586 | 6190
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

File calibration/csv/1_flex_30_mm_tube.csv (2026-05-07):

# Ghost Glove Flex Calibration — 30 mm tube
t_s | flex_ring | flex_middle | flex_index | flex_thumb
0.041 | 4596 | 6336 | 3482 | 6254
0.071 | 4563 | 6261 | 3398 | 6187
0.104 | 4683 | 6309 | 3437 | 6144
0.131 | 4613 | 6360 | 3568 | 6203
0.161 | 4502 | 6269 | 3450 | 6187
0.192 | 4603 | 6228 | 3430 | 6118
0.229 | 4622 | 6241 | 3510 | 6175
0.253 | 4483 | 6253 | 3453 | 6192
0.343 | 4582 | 6228 | 3340 | 6155
0.372 | 4660 | 6310 | 3377 | 6178
0.372 | 4588 | 6263 | 3427 | 6246
0.402 | 4570 | 6188 | 3307 | 6182
0.432 | 4717 | 6246 | 3381 | 6165
0.462 | 4606 | 6256 | 3486 | 6209
0.491 | 4558 | 6171 | 3376 | 6185
0.552 | 4631 | 6282 | 3388 | 6140
0.581 | 4614 | 6319 | 3520 | 6185
0.642 | 4468 | 6257 | 3422 | 6197
0.642 | 4502 | 6129 | 3414 | 6190
0.702 | 4605 | 6344 | 3388 | 6117
0.704 | 4623 | 6421 | 3475 | 6177
0.762 | 4487 | 6363 | 3427 | 6195
0.792 | 4583 | 6335 | 3312 | 6163
0.828 | 4659 | 6312 | 3439 | 6173
0.852 | 4586 | 6286 | 3456 | 6245
0.882 | 4568 | 6222 | 3348 | 6185
0.913 | 4715 | 6313 | 3428 | 6166
0.942 | 4603 | 6313 | 3533 | 6212
0.972 | 4554 | 6215 | 3417 | 6187
1.032 | 4628 | 6290 | 3411 | 6122
1.091 | 4612 | 6326 | 3522 | 6173
1.091 | 4486 | 6272 | 3429 | 6197
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

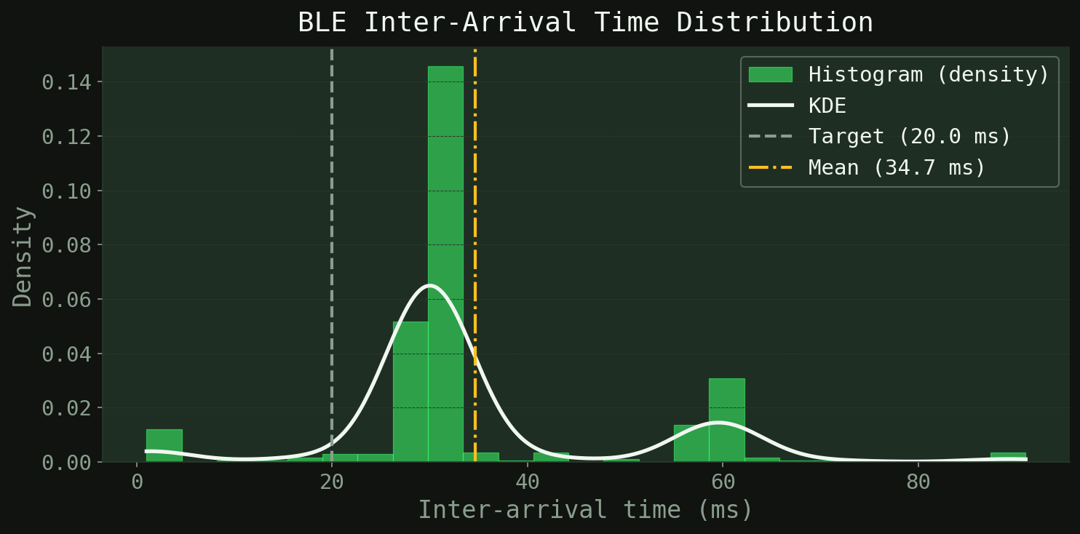
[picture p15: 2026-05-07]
calibration/plots/ble_histogram.png

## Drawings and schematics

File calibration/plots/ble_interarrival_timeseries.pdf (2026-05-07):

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

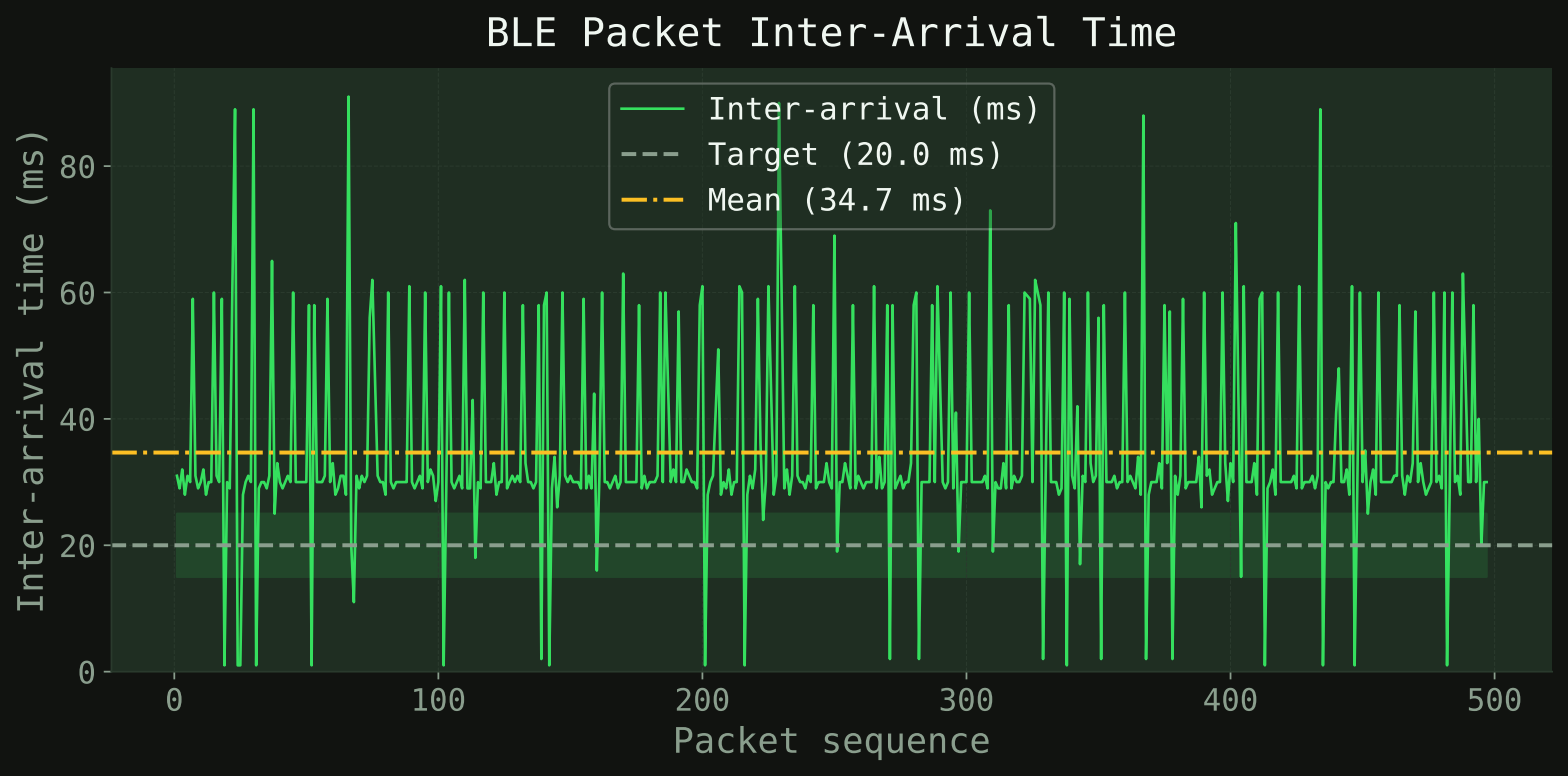
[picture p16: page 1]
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

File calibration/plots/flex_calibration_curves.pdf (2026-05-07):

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

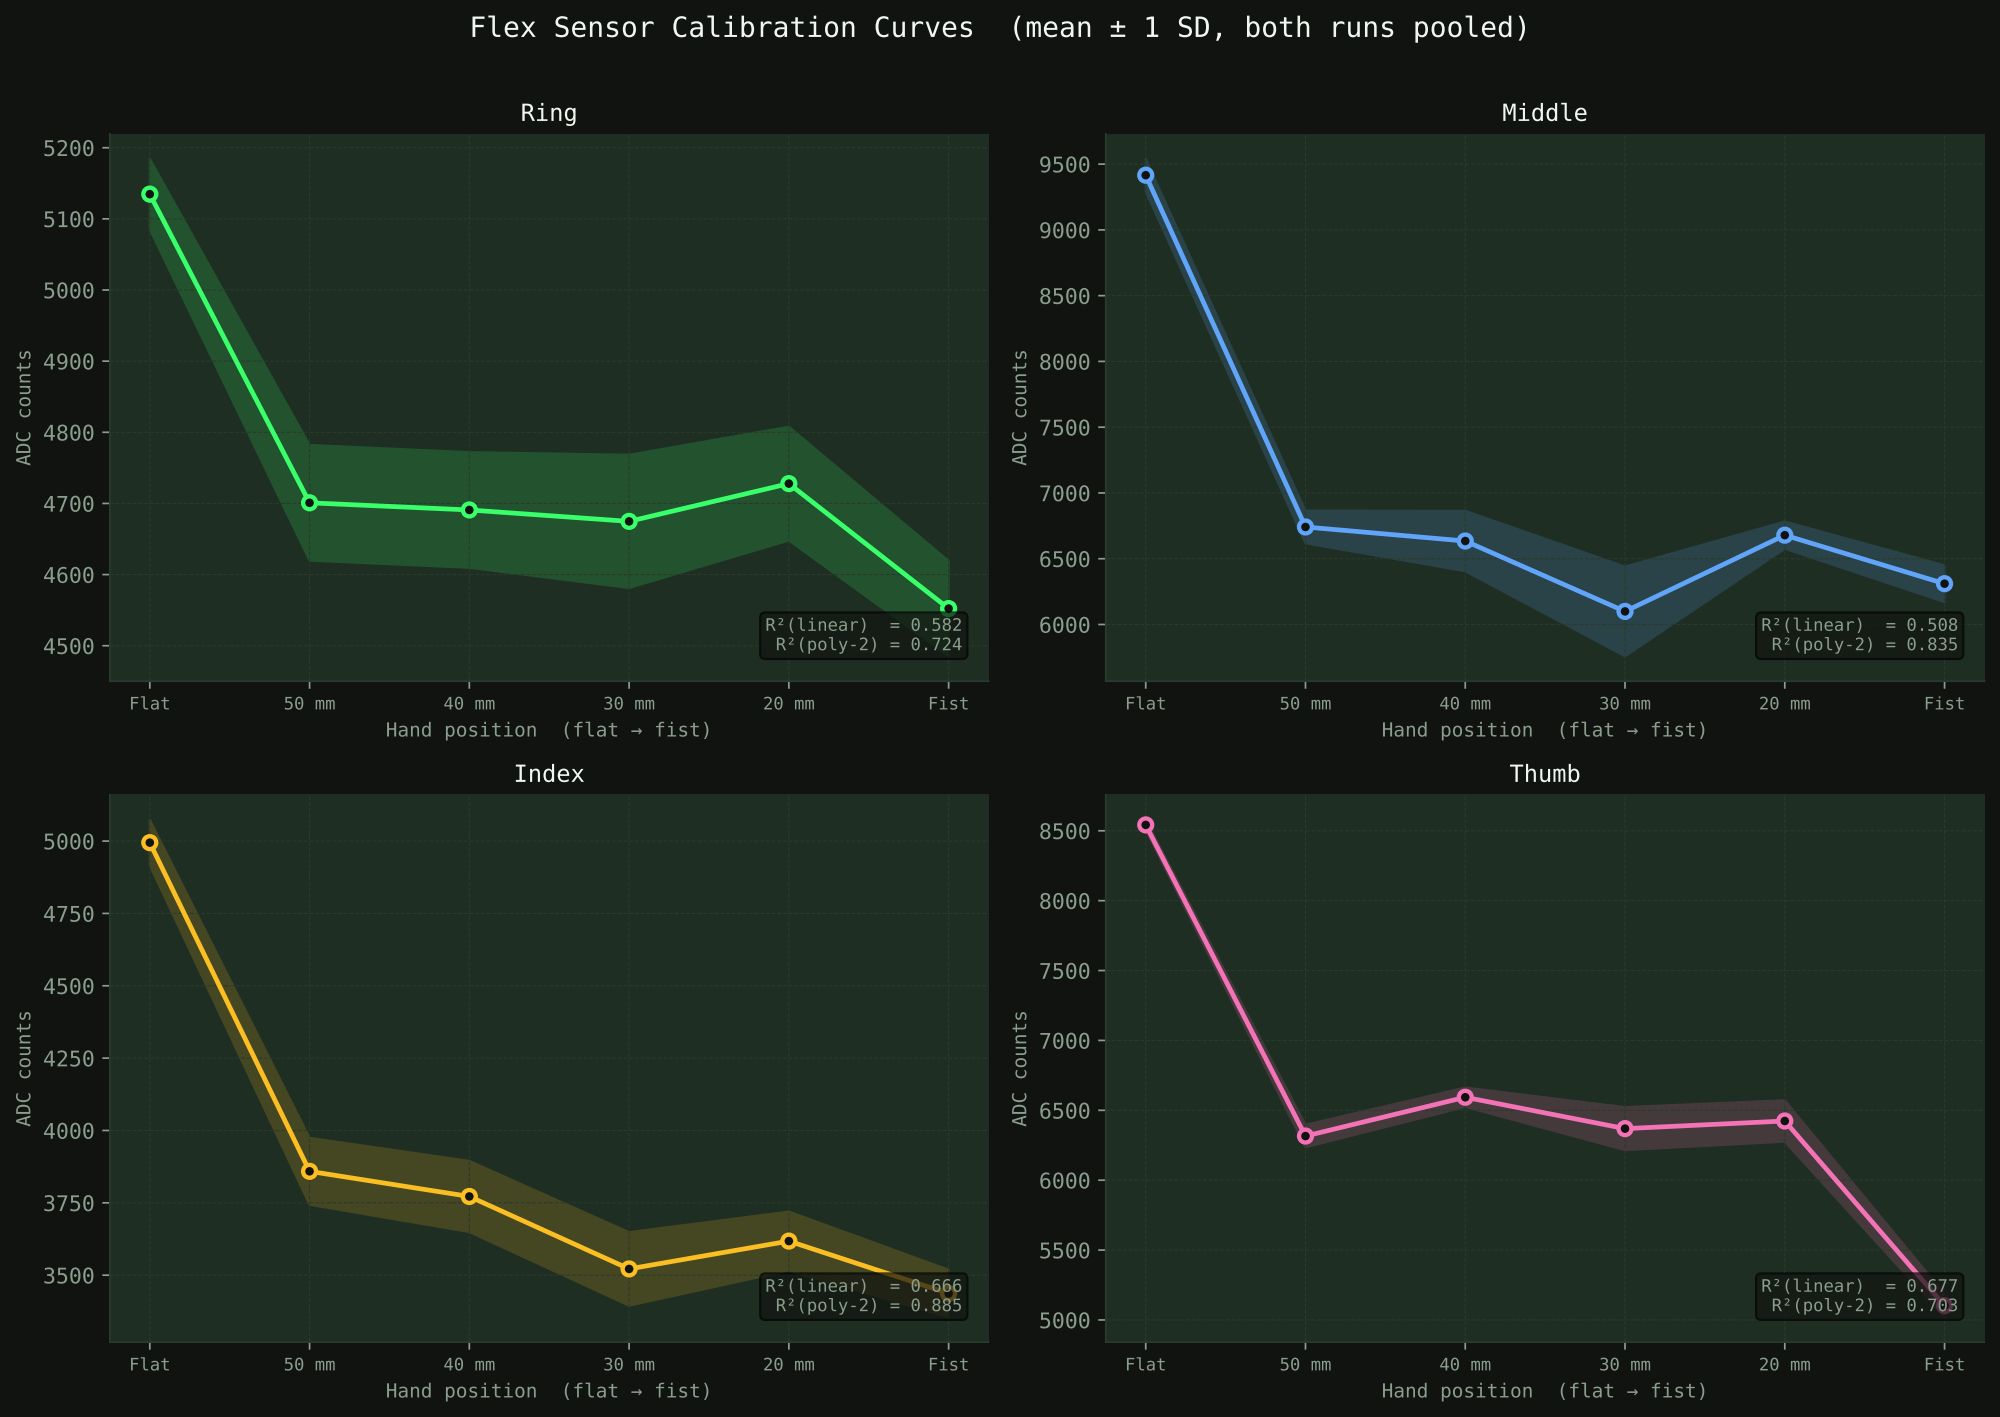
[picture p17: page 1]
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

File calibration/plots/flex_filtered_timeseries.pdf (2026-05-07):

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

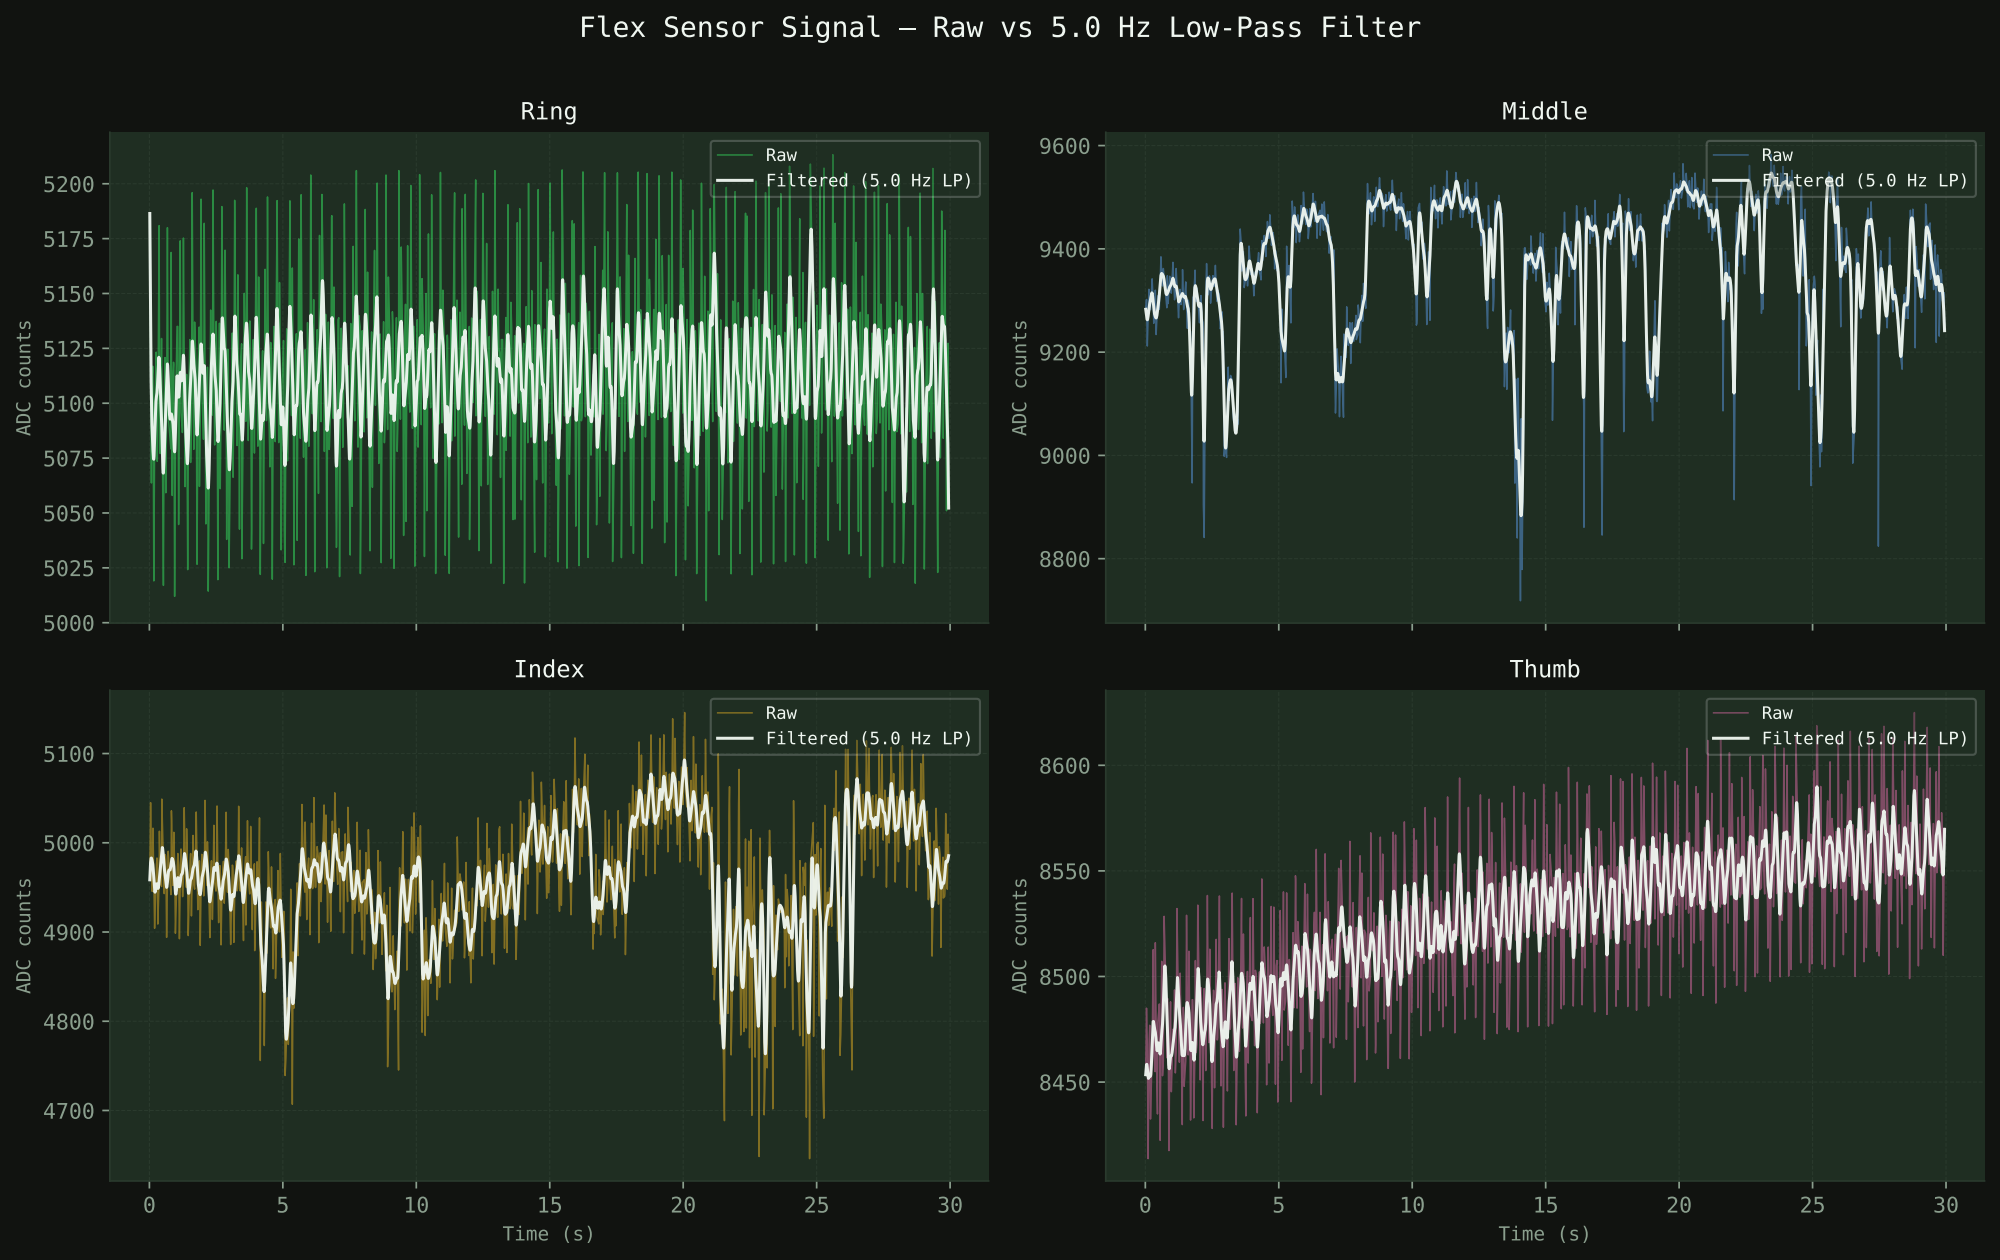
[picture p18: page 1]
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

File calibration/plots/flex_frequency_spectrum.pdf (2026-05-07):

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

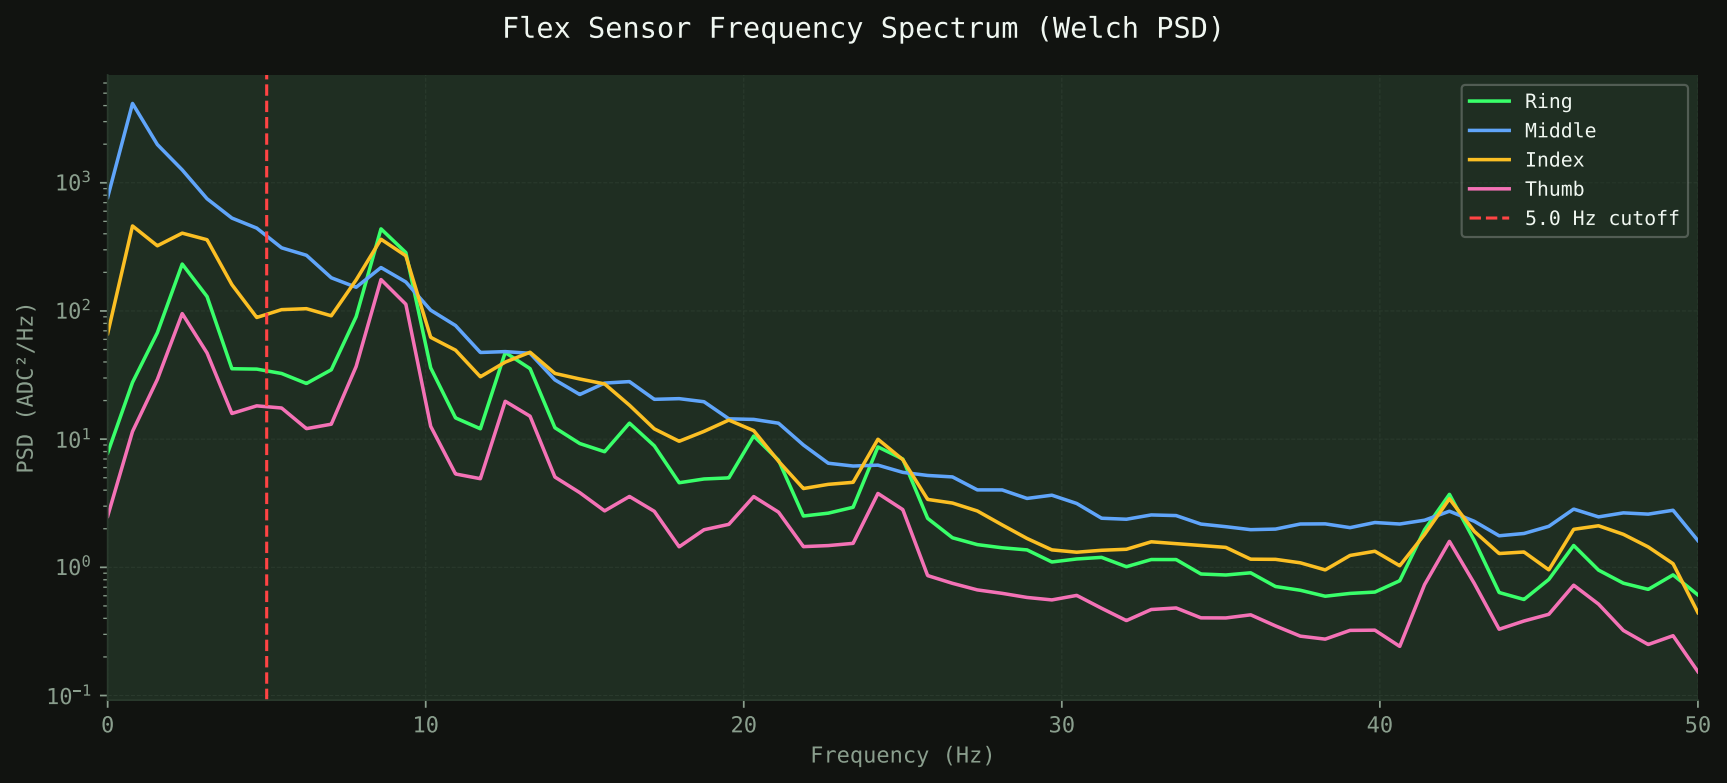
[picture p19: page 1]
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

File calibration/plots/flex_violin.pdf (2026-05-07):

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

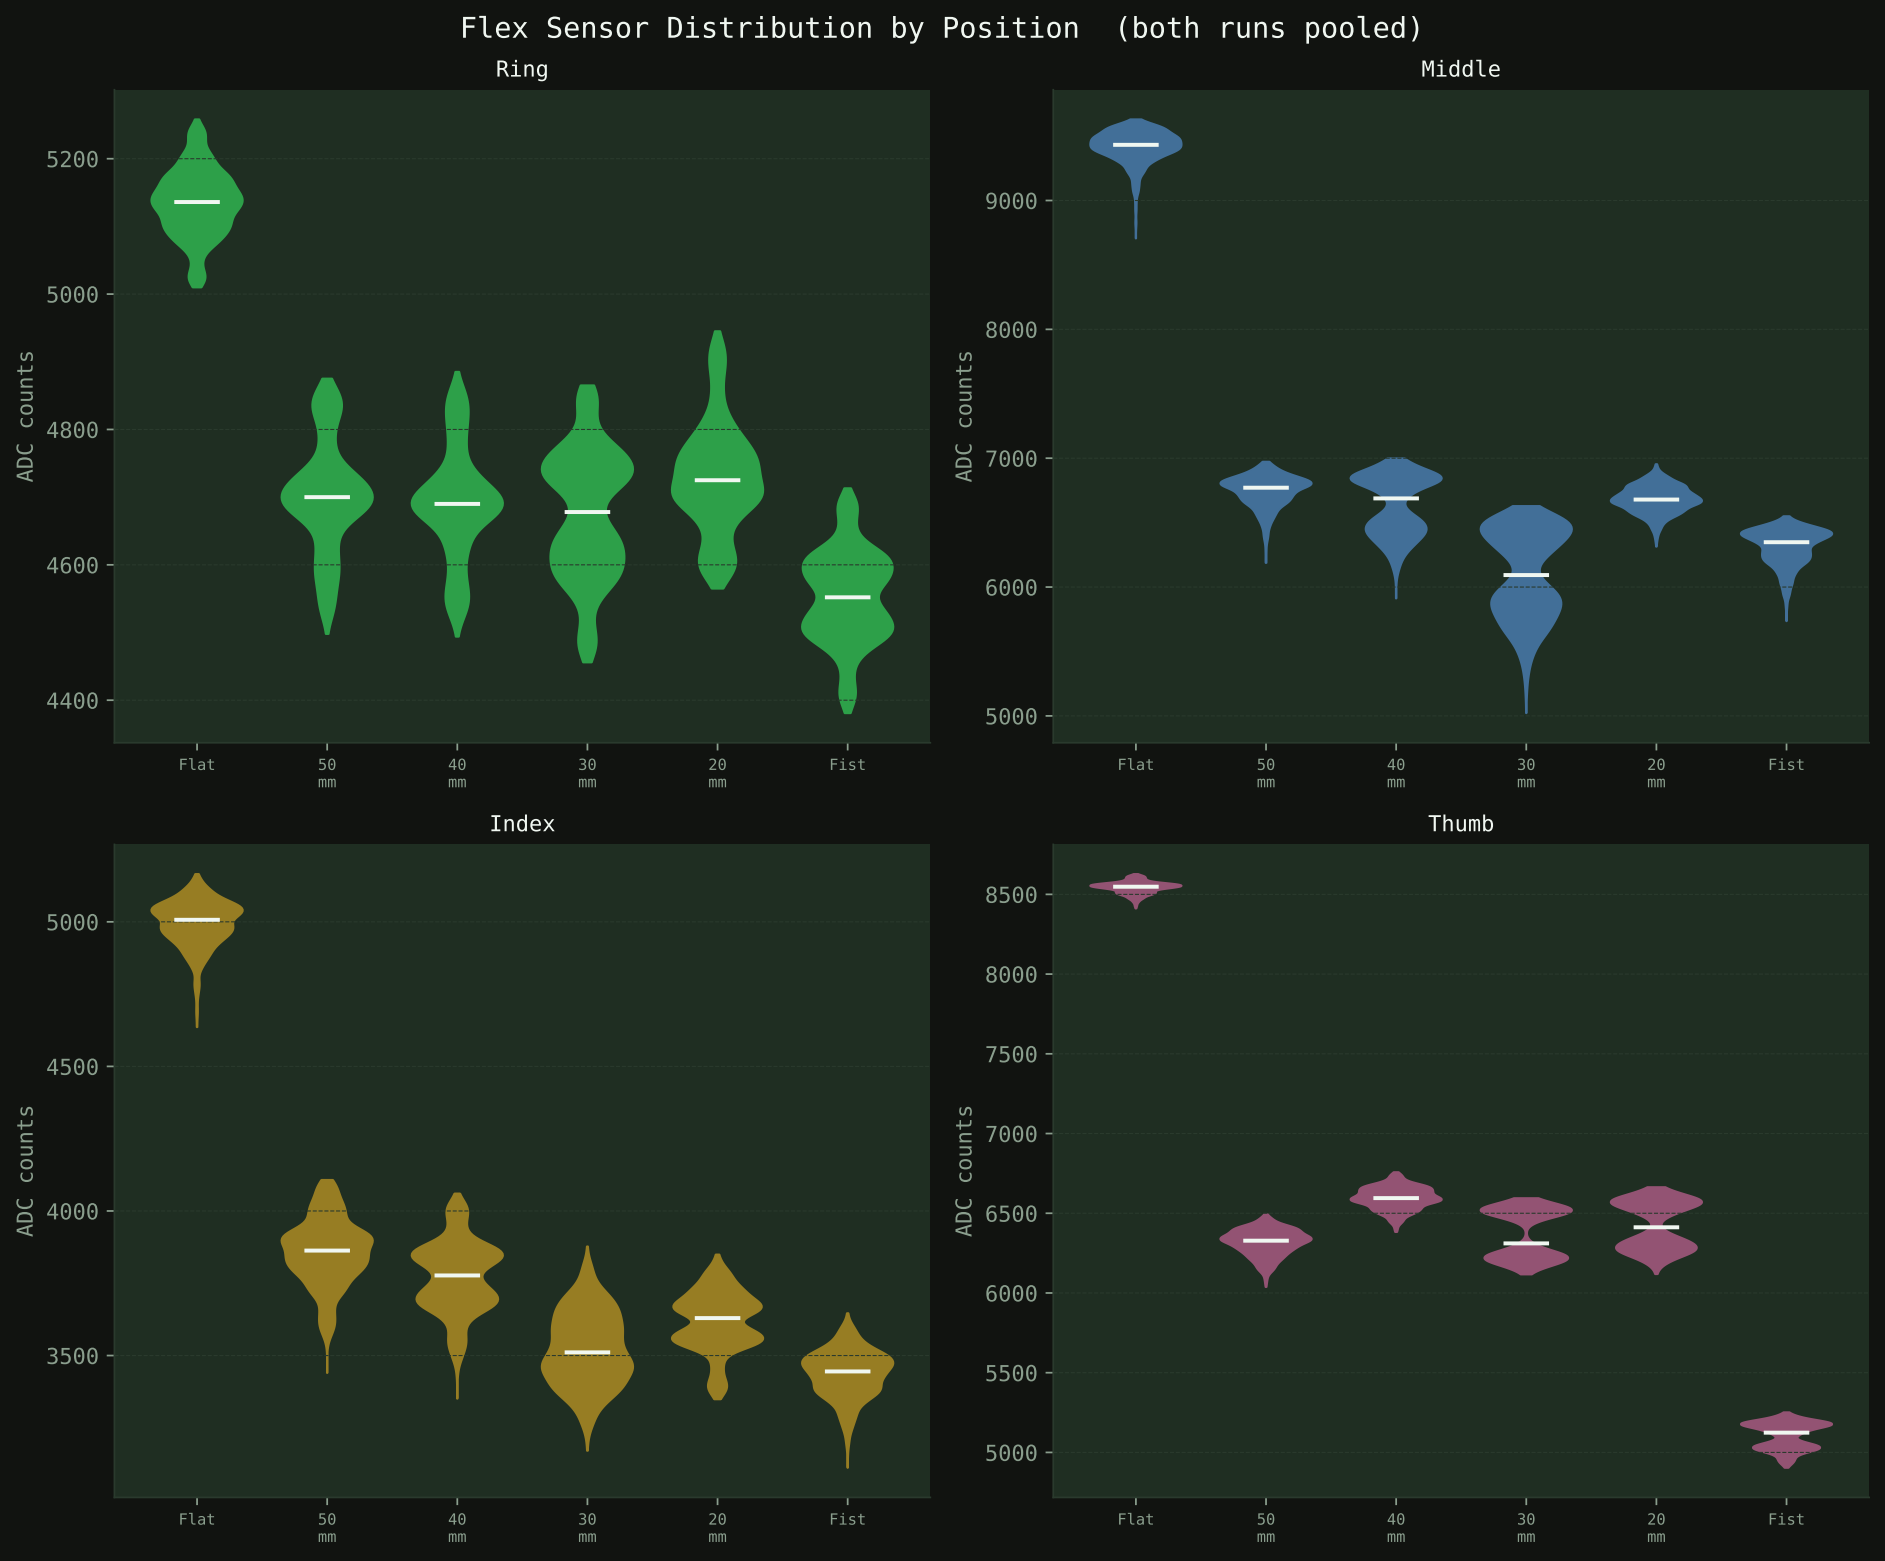
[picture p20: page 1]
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

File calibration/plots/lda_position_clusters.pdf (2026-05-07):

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

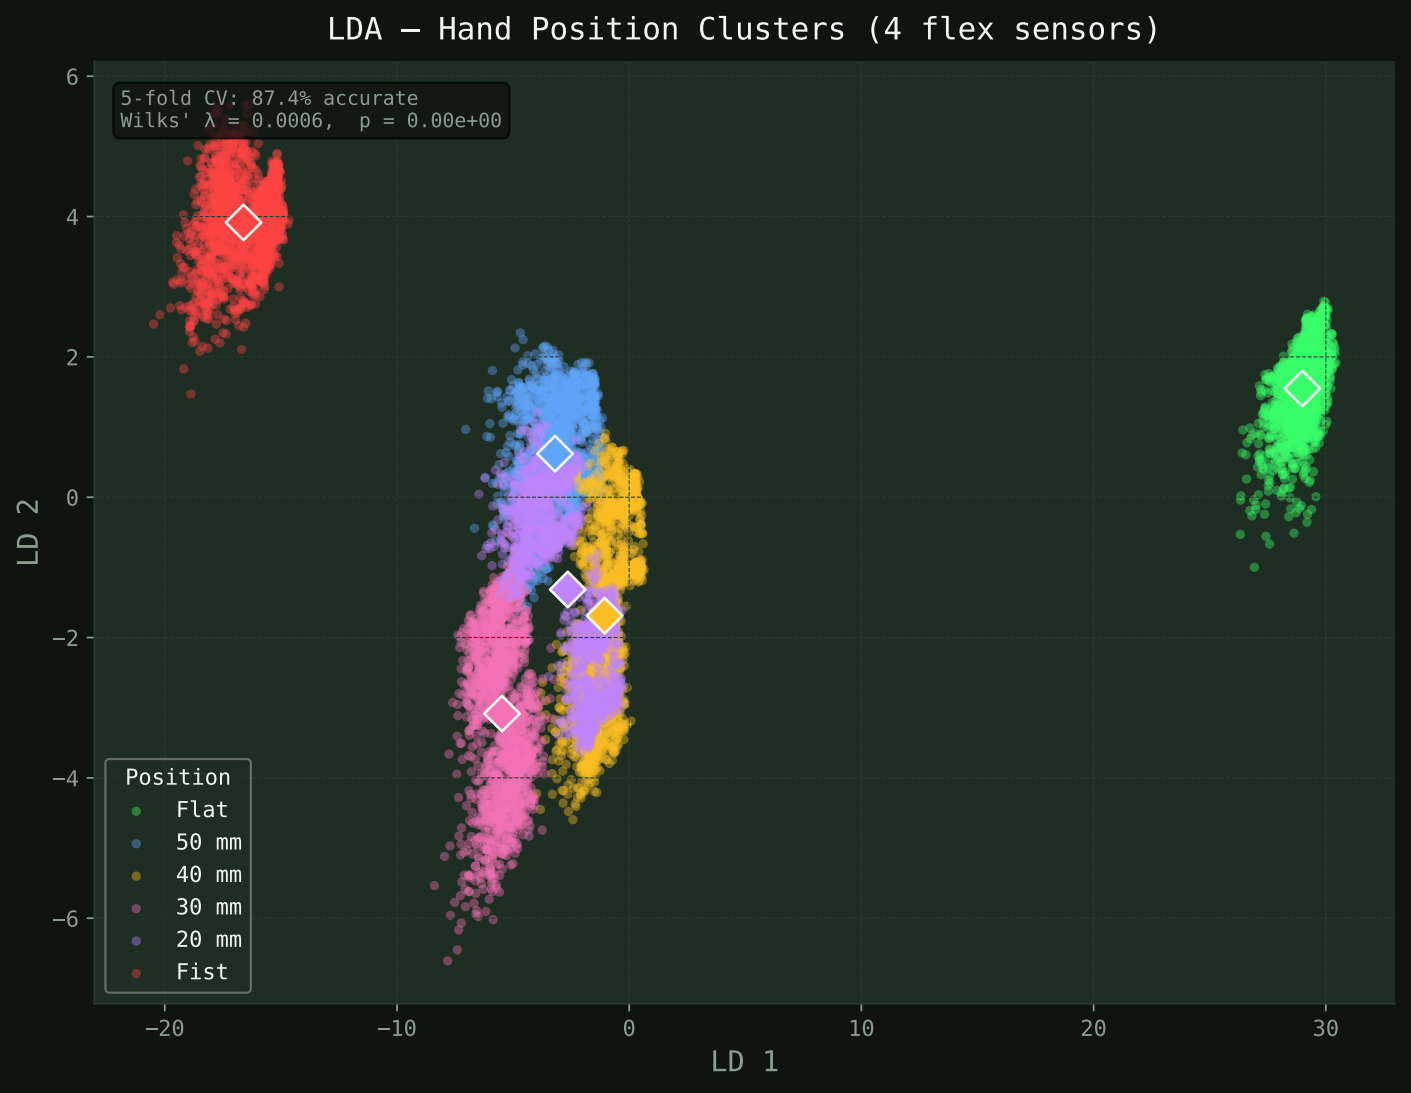
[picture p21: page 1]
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

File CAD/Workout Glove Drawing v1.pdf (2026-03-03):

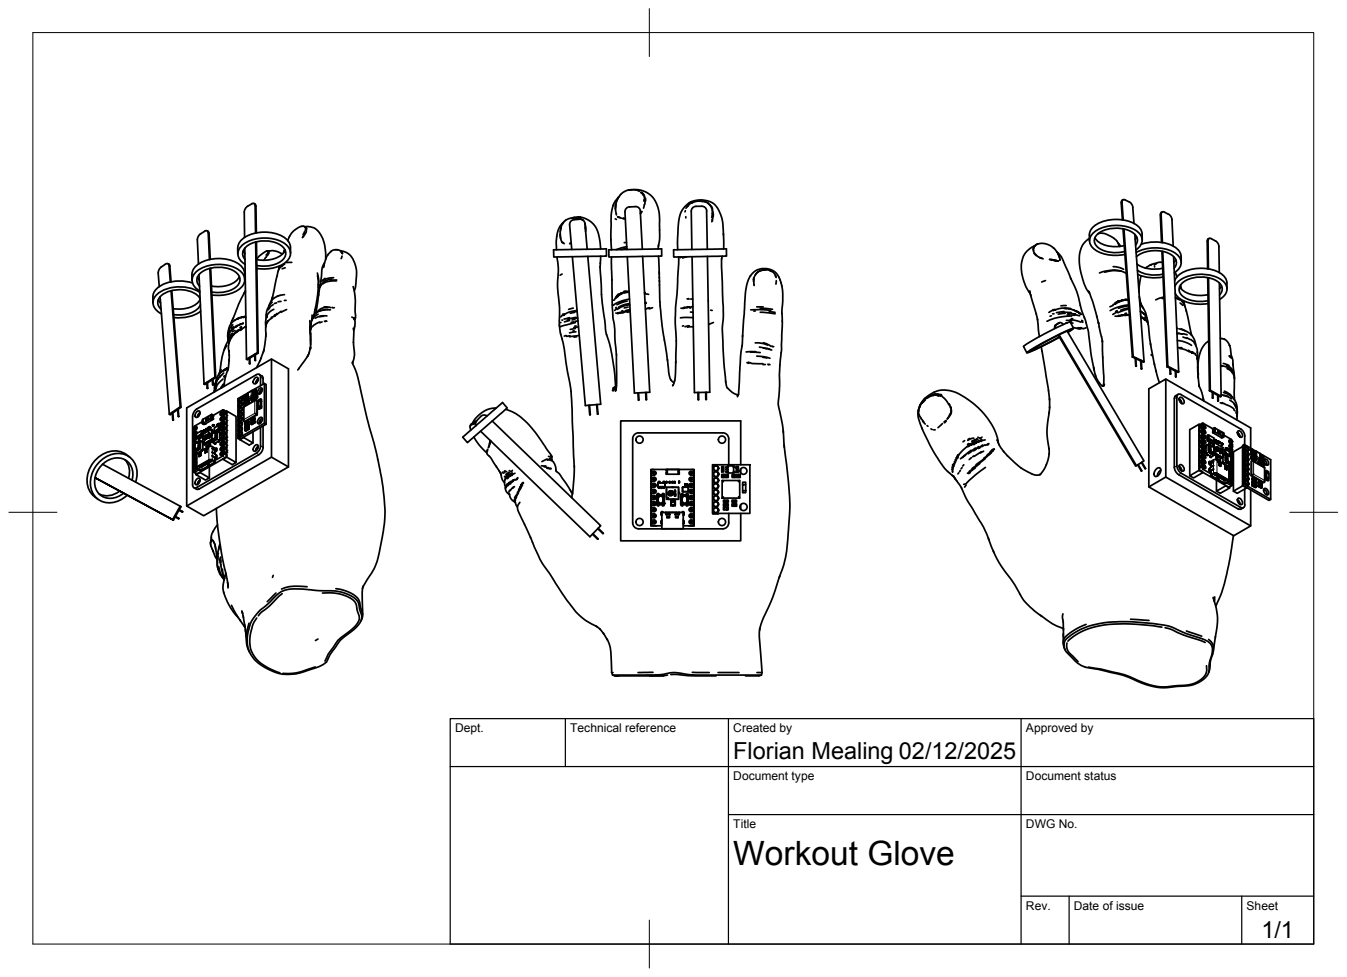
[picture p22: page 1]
Dept.; Technical reference; Created by; Approved by; Document type; Document status; Title; DWG No.; Rev.; Date of issue; Sheet; Workout Glove; Florian Mealing

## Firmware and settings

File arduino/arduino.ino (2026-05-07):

#include <Wire.h>
#include <Adafruit_MPU6050.h>
#include <Adafruit_Sensor.h>
#include <Adafruit_ADS1X15.h>
#include <BLEDevice.h>
#include <BLEServer.h>
#include <BLEUtils.h>
#include <BLE2902.h>
#include "rep_counting.h"

// ── Ghost Glove BLE UUIDs ──────────────────────────────────────────────────
#define GLOVE_SERVICE_UUID        "4fafc201-1fb5-459e-8fcc-c5c9c331914b"
#define GLOVE_CHARACTERISTIC_UUID "beb5483e-36e1-4688-b7f5-ea07361b26a8"

// ── Pins ───────────────────────────────────────────────────────────────────
const int SDA_PIN = 1;
const int SCL_PIN = 0;

// ── Peripherals ────────────────────────────────────────────────────────────
Adafruit_MPU6050 mpu;
Adafruit_ADS1115 ads;
BLECharacteristic* pCharacteristic = nullptr;

// ── Session state ──────────────────────────────────────────────────────────
bool     deviceConnected = false;
uint32_t sessionStart    = 0;
uint32_t repCount        = 0;

// ── BLE connection callbacks ───────────────────────────────────────────────
class ServerCallbacks : public BLEServerCallbacks {
    void onConnect(BLEServer* pServer) override {
        deviceConnected = true;
        sessionStart    = millis();
        repCount        = 0;
        Serial.println("[BLE] Client connected — session started");
    }
    void onDisconnect(BLEServer* pServer) override {
        deviceConnected = false;
        Serial.println("[BLE] Client disconnected — restarting advertising");
        BLEDevice::startAdvertising();
    }
};

// ── Packet helpers (little-endian) ────────────────────────────────────────
static void packFloat(uint8_t* buf, int offset, float val) {
    memcpy(buf + offset, &val, 4);
}
static void packUint32(uint8_t* buf, int offset, uint32_t val) {
    memcpy(buf + offset, &val, 4);
}

// ── Setup ──────────────────────────────────────────────────────────────────
void setup() {
    Serial.begin(115200);
    while (!Serial) delay(10);
    Wire.begin(SDA_PIN, SCL_PIN);

    // MPU6050
    if (!mpu.begin(0x68)) {
        Serial.println("[ERROR] MPU6050 not found!");
        while (1) delay(10);
    }
    mpu.setAccelerometerRange(MPU6050_RANGE_2_G);
    mpu.setGyroRange(MPU6050_RANGE_500_DEG);
    mpu.setFilterBandwidth(MPU6050_BAND_10_HZ);
    Serial.println("[OK] MPU6050 ready");

    // ADS1115
    if (!ads.begin(0x48)) {
        Serial.println("[ERROR] ADS1115 not found!");
        while (1) delay(10);
    }
    ads.setGain(GAIN_ONE);
    ads.setDataRate(RATE_ADS1115_860SPS);
    Serial.println("[OK] ADS1115 ready");

    // BLE
    BLEDevice::init("GhostGlove");
    BLEServer* pServer = BLEDevice::createServer();
    pServer->setCallbacks(new ServerCallbacks());

    BLEService* pService = pServer->createService(GLOVE_SERVICE_UUID);
    pCharacteristic = pService->createCharacteristic(
        GLOVE_CHARACTERISTIC_UUID,
        BLECharacteristic::PROPERTY_NOTIFY
    );
    pCharacteristic->addDescriptor(new BLE2902());
    pService->start();

    BLEAdvertising* pAdvertising = BLEDevice::getAdvertising();
    pAdvertising->addServiceUUID(GLOVE_SERVICE_UUID);
    pAdvertising->setScanResponse(true);
    BLEDevice::startAdvertising();
    Serial.println("[OK] BLE advertising as 'GhostGlove'");

    Serial.println("\n--- Live Readings (~50 Hz) ---");
}

// ── Loop ───────────────────────────────────────────────────────────────────
void loop() {
    // Read IMU
    sensors_event_t a, g, temp;
    mpu.getEvent(&a, &g, &temp);

    // Build ImuData and run full rep-counting pipeline
    ImuData raw;
    raw.acc     = {a.acceleration.x, a.acceleration.y, a.acceleration.z};
    raw.gyro    = {g.gyro.x, g.gyro.y, g.gyro.z};
    raw.time_ms = millis();

    repCount = updateRepCount(raw);

    // Read flex sensors (ADS1115 raw 16-bit counts, cast to float for BLE packet)
    float v0 = (float)ads.readADC_SingleEnded(0);
    float v1 = (float)ads.readADC_SingleEnded(1);
    float v2 = (float)ads.readADC_SingleEnded(2);
    float v3 = (float)ads.readADC_SingleEnded(3);

    // Build 48-byte BLE packet (little-endian)
    // Offsets:  0–11  accel x/y/z (float32, m/s²)
    //          12–23  gyro  x/y/z (float32, rad/s)
    //          24–39  flex  1–4   (float32, raw 16-bit ADC counts)
    //          40–43  rep_count   (uint32)
    //          44–47  timestamp   (uint32, ms since session start)
    uint8_t packet[48];
    packFloat(packet,  0, a.acceleration.x);
    packFloat(packet,  4, a.acceleration.y);
    packFloat(packet,  8, a.acceleration.z);
    packFloat(packet, 12, g.gyro.x);
    packFloat(packet, 16, g.gyro.y);
    packFloat(packet, 20, g.gyro.z);
    packFloat(packet, 24, v0);
    packFloat(packet, 28, v1);
    packFloat(packet, 32, v2);
    packFloat(packet, 36, v3);
    packUint32(packet, 40, repCount);
    packUint32(packet, 44, millis() - sessionStart);

    // Notify connected client
    if (deviceConnected) {
        pCharacteristic->setValue(packet, 48);
        pCharacteristic->notify();
    }

    // Serial debug
    Serial.printf("ACC  (m/s²) │ ax: %7.3f  ay: %7.3f  az: %7.3f\n",
        a.acceleration.x, a.acceleration.y, a.acceleration.z);
    Serial.printf("GYRO (rad/s)│ gx: %7.3f  gy: %7.3f  gz: %7.3f\n",
        g.gyro.x, g.gyro.y, g.gyro.z);
    Serial.printf("FLEX (raw)  │ A0: %.0f  A1: %.0f  A2: %.0f  A3: %.0f\n",
        v0, v1, v2, v3);
    Serial.printf("REP COUNT   │ %u  [%s]\n",
        repCount, deviceConnected ? "BLE connected" : "advertising");

    delay(20);  // ~50 Hz
}

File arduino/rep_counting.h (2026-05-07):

#pragma once
#define _USE_MATH_DEFINES
#include <cmath>
#include <algorithm>

/* -------------------- Constants -------------------- */
const int   cutoff_frequency_low_pass   = 10;       // Hz
const int   WINDOW_SAMPLES              = 100;      // 2s @ 50Hz
const int   MAX_INTERVALS               = 10;
const float cutoff_frequency_high_pass  = 0.5f;     // Hz
const float sensor_max_acc              = 19.62f;   // m/s^2, from sketch.ino
const float sensor_max_gyro             = 8.727f;   // rad/s, from sketch.ino
const float MADGWICK_BETA               = 0.1f;
const float VAR_THRESHOLD               = 0.30f;    // (m/s²)² — rest ≈0.02, curl ≈12

// MIDSV thresholds
const int   MIDSV_ENTER_MOTION_COUNT    = 10;       // consecutive high-var samples to enter MOTION
const int   MIDSV_EXIT_MOTION_COUNT     = 5;        // consecutive low-var samples to return to REST

// MCSV thresholds
const float MCSV_PEAK_THRESHOLD         = 0.45f;    // m/s² — minimum VM for a valid peak
const float MCSV_TROUGH_THRESHOLD       = -0.45f;   // m/s² — minimum VM for a valid trough

// IMU bias values (measured at 50 Hz over 20,000 samples, stationary)
const float BIAS_AX = -2.6284f;
const float BIAS_AY = -0.2492f;
const float BIAS_AZ = -0.0144f;
const float BIAS_GX = -0.1175f;
const float BIAS_GY =  0.0457f;
const float BIAS_GZ = -0.004f;

/* -------------------- Custom Types -------------------- */
struct Vector3 {
    float x, y, z;
};

struct ImuData {
    Vector3 acc;            // m/s^2
    Vector3 gyro;           // rad/s
    unsigned long time_ms;  // millis()
};

struct LowPassFilter {
    ImuData last_output;
    bool initialised;
};

struct HighPassFilter {
    float last_input;
    float last_output;
    bool initialised;
};

struct Quaternion {
    float w, x, y, z;
};

struct Integrator {
    float value;
    bool initialised;
};

struct SlidingWindow {
    float buffer[WINDOW_SAMPLES];
    int head;
    int count;
};

struct MotionInterval {
    unsigned long start_ms;
    unsigned long end_ms;
};

struct MotionLog {
    MotionInterval intervals[MAX_INTERVALS];
    int count;
};

/* -------------------- MIDSV State -------------------- */
enum MidsvState { MIDSV_REST, MIDSV_MOTION };

/* -------------------- MCSV State -------------------- */
enum McsvState { MCSV_IDLE, MCSV_ASCENDING, MCSV_DESCENDING };

/* -------------------- Helper Functions -------------------- */
static float clamp(float x, float low, float high) {
    return x < low ? low : (x > high ? high : x);
}

Quaternion conjugate(Quaternion q) {
    return {q.w, -q.x, -q.y, -q.z};
}

Quaternion multiplyQuarternions(Quaternion a, Quaternion b) {
    return {
        a.w*b.w - a.x*b.x - a.y*b.y - a.z*b.z,
        a.w*b.x + a.x*b.w + a.y*b.z - a.z*b.y,
        a.w*b.y - a.x*b.z + a.y*b.w + a.z*b.x,
        a.w*b.z + a.x*b.y - a.y*b.x + a.z*b.w
    };
}

/* -------------------- Action Functions -------------------- */

/*
 * Subtract calibrated bias values from raw IMU data
 * Input:  ImuData raw
 * Output: ImuData with bias removed
 */
ImuData applyBiasCorrection(ImuData current) {
    current.acc.x  -= BIAS_AX;
    current.acc.y  -= BIAS_AY;
    current.acc.z  -= BIAS_AZ;
    current.gyro.x -= BIAS_GX;
    current.gyro.y -= BIAS_GY;
    current.gyro.z -= BIAS_GZ;
    return current;
}

/*
 * Apply a low-pass filter to IMU data
 * Equation: filtered[n] = alpha * x[n] + (1 - alpha) * filtered[n-1]
 * Constants: cutoff_frequency_low_pass
 */
ImuData applyLowPassFilter(ImuData current, LowPassFilter &filter) {
    if (!filter.initialised) {
        filter.last_output = current;
        filter.initialised = true;
        return current;
    }

    float dt = (current.time_ms - filter.last_output.time_ms) / 1000.0f;
    float RC = 1.0f / (2.0f * M_PI * cutoff_frequency_low_pass);
    float alpha = dt / (dt + RC);

    ImuData filtered;
    filtered.time_ms = current.time_ms;

    filtered.acc.x = alpha * current.acc.x + (1 - alpha) * filter.last_output.acc.x;
    filtered.acc.y = alpha * current.acc.y + (1 - alpha) * filter.last_output.acc.y;
    filtered.acc.z = alpha * current.acc.z + (1 - alpha) * filter.last_output.acc.z;

    filtered.gyro.x = alpha * current.gyro.x + (1 - alpha) * filter.last_output.gyro.x;
    filtered.gyro.y = alpha * current.gyro.y + (1 - alpha) * filter.last_output.gyro.y;
    filtered.gyro.z = alpha * current.gyro.z + (1 - alpha) * filter.last_output.gyro.z;

    filter.last_output = filtered;
    return filtered;
}

/*
 * Normalise IMU data to [-1, 1]
 * Equation: normalised = clamp(x / sensor_max, -1, 1)
 */
ImuData normaliseImu(ImuData current) {
    ImuData normalised;

    normalised.acc.x = clamp(current.acc.x / sensor_max_acc, -1.0f, 1.0f);
    normalised.acc.y = clamp(current.acc.y / sensor_max_acc, -1.0f, 1.0f);
    normalised.acc.z = clamp(current.acc.z / sensor_max_acc, -1.0f, 1.0f);

    normalised.gyro.x = clamp(current.gyro.x / sensor_max_gyro, -1.0f, 1.0f);
    normalised.gyro.y = clamp(current.gyro.y / sensor_max_gyro, -1.0f, 1.0f);
    normalised.gyro.z = clamp(current.gyro.z / sensor_max_gyro, -1.0f, 1.0f);

    normalised.time_ms = current.time_ms;
    return normalised;
}

/*
 * Apply a high-pass filter to a scalar signal
 * Equation: filtered[n] = alpha * (filtered[n-1] + x[n] - x[n-1])
 * where alpha = RC / (RC + dt), RC = 1 / (2 * pi * cutoff_hz)
 */
float applyHighPassFilter(float input, float dt, float cutoff_hz, HighPassFilter &filter) {
    if (!filter.initialised) {
        filter.last_input  = input;
        filter.last_output = 0.0f;
        filter.initialised = true;
        return 0.0f;
    }

    float RC = 1.0f / (2.0f * M_PI * cutoff_hz);
    float alpha = RC / (RC + dt);
    float output = alpha * (filter.last_output + input - filter.last_input);

    filter.last_input  = input;
    filter.last_output = output;
    return output;
}

/*
 * Compute vector-magnitude acceleration centred on 1g
 * Output: sqrt(ax² + ay² + az²) − 9.81, ≈ 0 when stationary
 */
float computeVMAccel(ImuData current) {
    float ax = current.acc.x, ay = current.acc.y, az = current.acc.z;
    return sqrtf(ax*ax + ay*ay + az*az) - 9.81f;
}

/*
 * Add a sample to the sliding window ring buffer
 */
void addSample(SlidingWindow &window, float value) {
    window.buffer[window.head] = value;
    window.head = (window.head + 1) % WINDOW_SAMPLES;
    if (window.count < WINDOW_SAMPLES) window.count++;
}

/*
 * Compute variance over the sliding window
 * Equation: Var = (1/N) * Sum(x_i - mean)^2
 */
float computeVariance(SlidingWindow &window) {
    if (window.count == 0) return 0.0f;

    float sum = 0.0f;
    for (int i = 0; i < window.count; i++) sum += window.buffer[i];
    float mean = sum / window.count;

    float sq_sum = 0.0f;
    for (int i = 0; i < window.count; i++) {
        float diff = window.buffer[i] - mean;
        sq_sum += diff * diff;
    }
    return sq_sum / window.count;
}
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

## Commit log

2026-03-03 [Feat] Added the Fusion360 files
    [Workout Glove Concept.f3z, finger rings v1.f3d]
2026-03-03 [Feat] Updated the prototype picture
2026-03-08 [Feat] Added the Low Pass Filter
2026-03-08 [Feat] Implemented the high-pass filter
2026-03-09 [Feat] Implemented a simulated version of the code
    [output.csv]
2026-03-09 [Feat] implemented the rep counting algorithm with the arduino code as well
2026-03-13 [Fix] Fixed a majour issue with the approach
    [calibrate_imu.ino, rep_counting.h]
2026-05-07 [Feat] Final dump before report submission
    [1_flex_20_mm_tube.csv, 1_flex_30_mm_tube.csv, 1_flex_40_mm_tube.csv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]
